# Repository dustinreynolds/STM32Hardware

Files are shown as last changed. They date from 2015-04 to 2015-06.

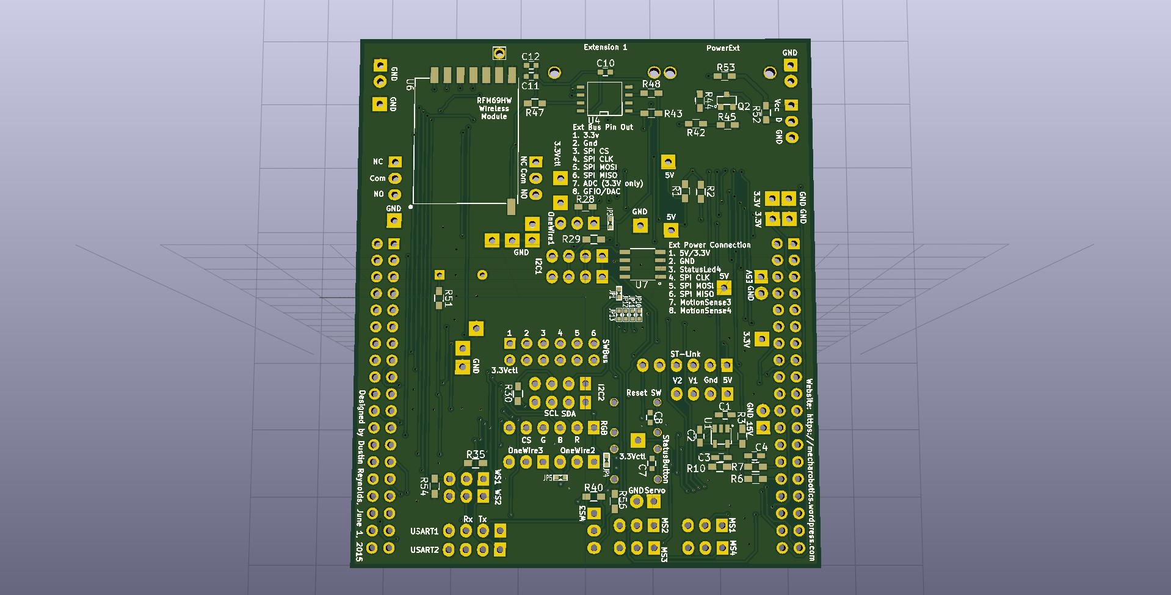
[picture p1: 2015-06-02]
Nucleo_L152RE/ProtoBoard/AB/ProtoBoard_AB_Back.jpg

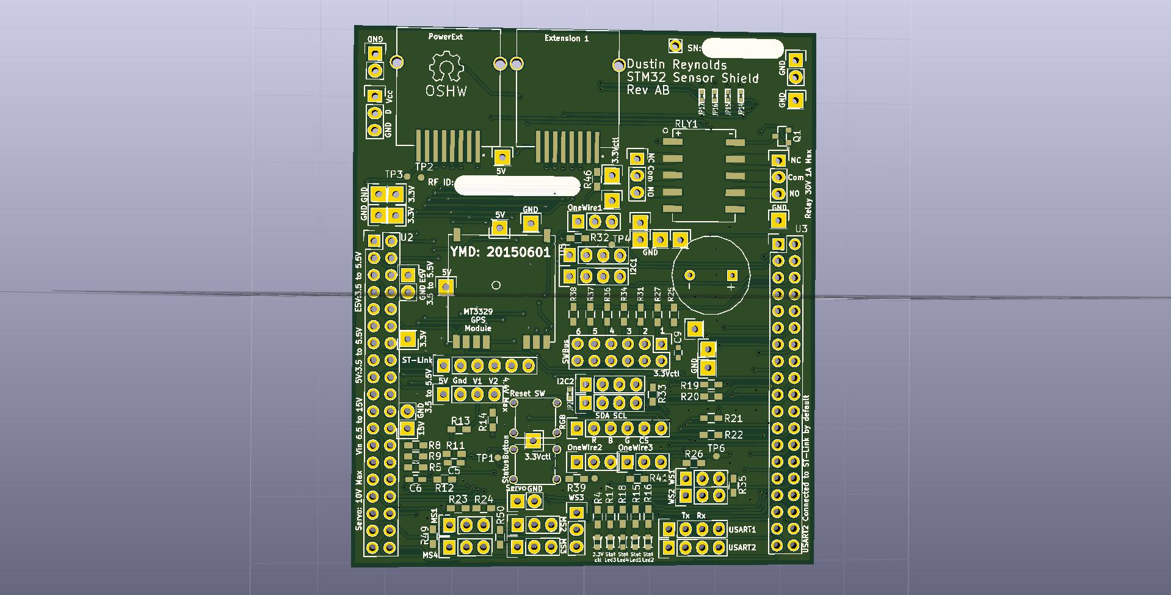
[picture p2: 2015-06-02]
Nucleo_L152RE/ProtoBoard/AB/ProtoBoard_AB_Front.jpg

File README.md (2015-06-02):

# STM32Hardware
Repository for Kicad board development and support libraries

This repository was created on Windows using Kicad built from source using [kicad-winbuilder3.4](https://launchpad.net/kicad-winbuilder).

## Folder Hierarchy 
* Calculations - Brief calculations performed
* kicad_lib - Libraries created for new schematic or pcb objects
* Nucleo_L152RE - contains board designs that have been designed using Kicad build on 2015-05-11 from BZR commit 5650.

## Hardware Releases
So far none of the designs in this repository have been tested and verified to be working.  Footprints have been aligned with the actual components, but until the actual PCB's and the remaining components arrive, this repository should serve as a reference only.  This readme will be updated to reflect the latest testing status.

ProtoBoard Rev AA had the following issues:
	Using 5 pins from morpheo headers that didn't have a pin on them.
	RFM69HW footprint was backwards for part of it.
	See AA schematics for additional notes.

Protoboard Rev AB made the following changes:
	Removed USB, replaced with low voltage relay and fet
	Added Crypto chip ATSHA204A to i2c bus
	Added GPS to I2C bus (those same pins can be used as USART)
	Split schematic into 5 pages to ease readability
	Added 5V in and use that as main power input signal (this leaves programmer unpowered)
	Added additional voltage sense pins on 5V connector for monitoring state of battery pack
	Added 3.3V regulator that can be controlled via enable pin.  This is so SPI/I2C/OneWire devices can be powered off easily.  On board chips have low power requirements when asleep.
	Added additional spare Gnd, 3.3V, 3.3Vctl, and 5.0V lines for expansion.
	Added Servo power input for motionsense 1 and 2 (which are also pwm pins)
	Added piezo buzzer on OneWire3
	Added CS pin for RGB connector since it can be a spare SPI
	Removed mounting holes since this is securely mounted to Nucleo board.

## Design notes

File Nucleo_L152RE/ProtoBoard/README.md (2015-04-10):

# STM32L152RE

The STM32 L series offers low power sleep modes that can be easily utilized to form a network of low power sensing nodes which each have the power of a 32-bit ARM Cortex M3 processor.  This board was designed to leverage these low power modes by adding high power wireless modules with low sleep currents and an on-expansion-board 128 Mb FLASH chip for offline sensor measurements.

THe STM32L152RE has 512KB of flash, 80 KB Ram and ECC backed 16KB EEPROM.  The most compelling feature was the [OpenSTM32](OpenSTM32.org) System Workbench for STM32.  Utilizing an Eclipse base IDE, Eclipse plugins are installed which give you a relatively seamless transition from writing code to debugging it.  The debugger is OpenOCD, utilizing the ST-Link. There are growing pains when transitioning to any platform, but the performance and recent availability of high quality tools make the STM32 a hot platform to start projects on. 

Development boards for a wide range of STM32 processors can be found for under $11.  Although each of those development boards only offer 64 pin packages of each respective processor, much can be done with that core subset of pins.

# Kicad Schematics and Printed Circuit Boards

## ProtoBoard
First Kicad release for the Nucleo-L152RE development board. This development board will serve as a low power platform for performing sensor measurements around my house.  Each STM32 expansion board will contain an RFM69HW wireless transceiver and will be capable of broadcasting events to the wireless network.  A listening device will then notify the owner of the event so that rapid action can occur.

### Event Detection and Alerting
The following events will be monitored
* Water leak (toilets, AC drip pan, Water Heater)
* Room temperature
* Stove burner or oven left on
* Door/window opens or closes
* Plant moisture sensing
* Dryer temperature and timing

### Firmware
The associated firmware can be found at the [SensorNodes Project](https://github.com/dustinreynolds/SensorNodes/tree/develop).  The Git-Flow paradigm is in use, so code can be found in the develop branch until a functioning first release is released, at which point it will be in the master branch (and show up by default on Github).

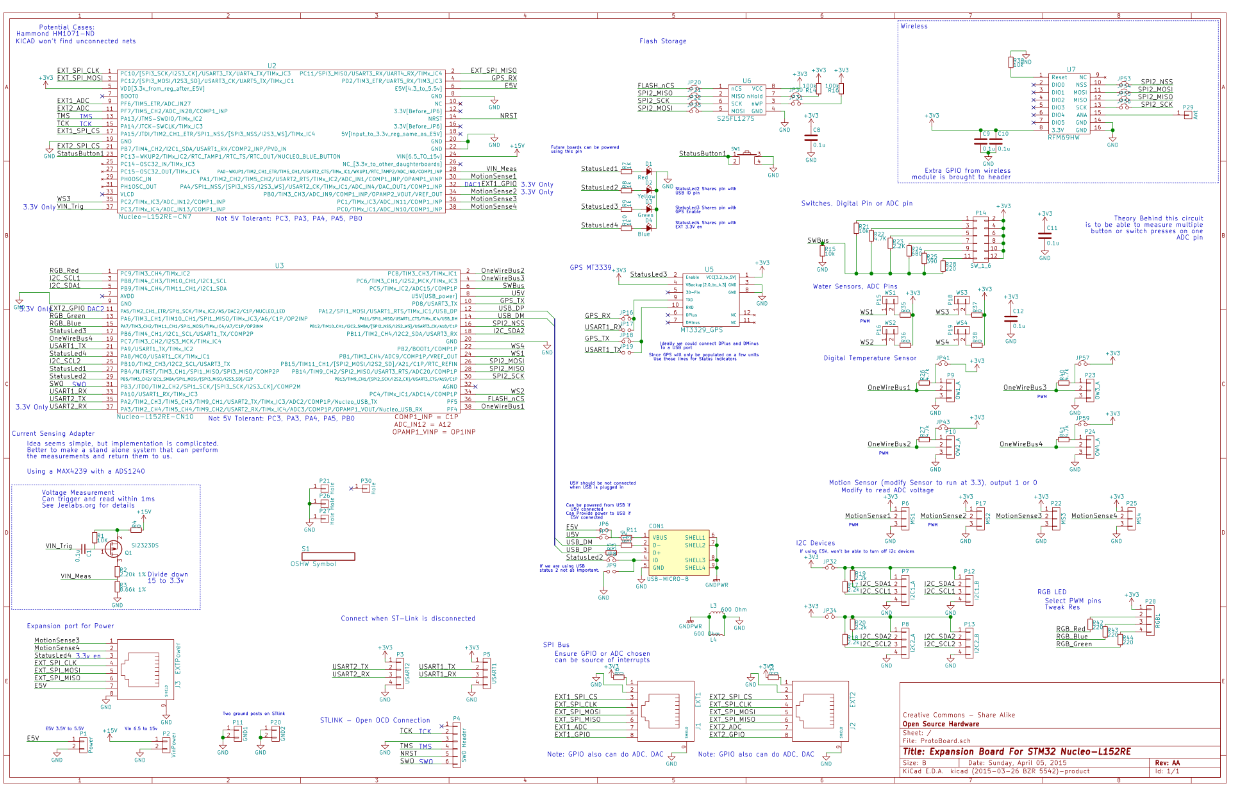
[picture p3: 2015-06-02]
Nucleo_L152RE/ProtoBoard/AA/Schematics.png

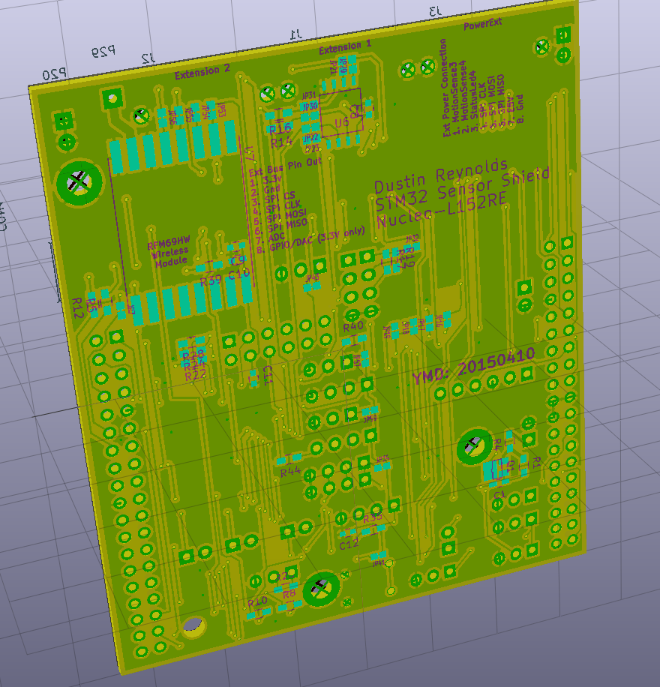
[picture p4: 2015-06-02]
Nucleo_L152RE/ProtoBoard/AA/3d_view_board.png

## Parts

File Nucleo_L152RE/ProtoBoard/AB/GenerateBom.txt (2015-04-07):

To generate bom:
	In Kicad, Click BOM.   Choose bom2csv or bom_cvs and click generate
	In folder, click Update_BOM.bat.  New *.csv will be created.

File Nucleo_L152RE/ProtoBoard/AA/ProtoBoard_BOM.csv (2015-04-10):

Source: | C:/Customers/Dustin/SensorNodes/STM32/EE/Nucleo_L152RE/ProtoBoard/AA/ProtoBoard.sch
Date: | 4/10/2015 3:52:45 PM
Tool: | Eeschema (2015-03-26 BZR 5542)-product
Generator: | dustin_bom_csv_grouped_by_value_with_fp.py
Component Count: | 116
Ref | Quantity | Value | Cmp name | Footprint | Description | Vendor | Datasheet | Digikey Part Number | Digikey URL | Mouser Part Number | Mouser URL | Ebay | Manufacture Part Number
C1, | 1 | 0.1u | C_Small | Capacitors_SMD:C_0603_HandSoldering | Unpolarized capacitor |  | http://www.digikey.com/product-detail/en/GRM188R71C104KA01D/490-1532-1-ND/587771 | 490-1532-1-ND |  |  |  |  | GRM188R71C104KA01D
C10, C9, C8, C11, C12, | 5 | 0.1u | C | Capacitors_SMD:C_0603 | Unpolarized capacitor |  |  | 490-1532-1-ND |  |  |  |  | GRM188R71C104KA01D
CON1, | 1 | USB-MICRO-B | USB-MICRO-B | nucleo:USB_micro_AB | USB Mini B connector |  | http://www.digikey.com/product-detail/en/10104111-0001LF/609-4053-1-ND/2350359 | 609-4053-1-ND | http://www.digikey.com/product-detail/en/10104111-0001LF/609-4053-1-ND |  |  |  | 10104111-0001LF
D1, | 1 | Red | Led_Small | nucleo:LED_0603 | Led |  | http://optoelectronics.liteon.com/upload/download/DS22-2000-223/S_110_LTST-C191KRKT.pdf | 160-1447-1-ND | http://www.digikey.com/product-detail/en/LTST-C191KRKT/160-1447-1-ND/386836 |  |  |  | LTST-C191KRKT
D2, | 1 | Yellow | Led_Small | nucleo:LED_0603 | Led |  | http://optoelectronics.liteon.com/upload/download/DS22-2000-224/S_110_LTST-C191KSKT.pdf | 160-1448-1-ND | http://www.digikey.com/product-detail/en/LTST-C191KSKT/160-1448-1-ND |  |  |  | LTST-C191KSKT
D3, | 1 | Green | Led_Small | nucleo:LED_0603 | Led |  | http://optoelectronics.liteon.com/upload/download/DS22-2000-228/S_110_LTST-C191KGKT.pdf | 160-1446-1-ND | http://www.digikey.com/product-detail/en/LTST-C191KGKT/160-1446-1-ND |  |  |  | LTST-C191KGKT
D4, | 1 | Blue | Led_Small | nucleo:LED_0603 | Led |  | http://optoelectronics.liteon.com/upload/download/DS22-2000-230/S_110_LTST-C191TBKT.pdf | 160-1647-1-ND | http://www.digikey.com/product-detail/en/LTST-C191TBKT/160-1647-1-ND |  |  |  | LTST-C191TBKT
J1, | 1 | EXT1 | RJ45 | nucleo:RJ45_SMD |  |  | http://www.digikey.com/product-detail/en/RJLSE4238101T/RJLSE4238101TTR-ND/1979556 | RJLSE4238101TTR-ND | http://www.digikey.com/product-detail/en/RJLSE4238101T/RJLSE4238101TTR-ND/1979556 |  |  |  | RJLSE4238101T
J2, | 1 | EXT2 | RJ45 | nucleo:RJ45_SMD |  |  | http://www.digikey.com/product-detail/en/RJLSE4238101T/RJLSE4238101TTR-ND/1979556 | RJLSE4238101TTR-ND | http://www.digikey.com/product-detail/en/RJLSE4238101T/RJLSE4238101TTR-ND/1979556 |  |  |  | RJLSE4238101T
J3, | 1 | EXTPower | RJ45 | nucleo:RJ45_SMD |  |  | http://www.digikey.com/product-detail/en/RJLSE4238101T/RJLSE4238101TTR-ND/1979556 | RJLSE4238101TTR-ND | http://www.digikey.com/product-detail/en/RJLSE4238101T/RJLSE4238101TTR-ND/1979556 |  |  |  | RJLSE4238101T
JP19, JP17, JP9, JP6, | 4 | Jumper_NO_Small | Jumper_NO_Small | nucleo:SB_NO | Jumper normally open
JP53, JP54, JP55, JP56, JP20, JP21, JP22, JP23, JP30, JP31, JP16, JP18, JP8, JP34, JP32, JP7, JP41, JP57, JP59, JP43, | 20 | Jumper_NC_Small | Jumper_NC_Small | nucleo:SB_NC | Jumper normally close
L4, L3, | 2 | 600 Ohm | L_Small | Resistors_SMD:R_0603_HandSoldering | Inductor |  | http://www.digikey.com/product-detail/en/MI0603J601R-10/240-2371-1-ND/806731 | 240-2371-1-ND | http://www.digikey.com/product-detail/en/MI0603J601R-10/240-2371-1-ND/ |  |  |  | MI0603J601R-10
P1, | 1 | Power | CONN_01X02 | Pin_Headers:Pin_Header_Straight_1x02
P10, | 1 | OW2_A | CONN_01X03 | Pin_Headers:Pin_Header_Straight_1x03
P11, | 1 | GND1 | CONN_01X02 | Pin_Headers:Pin_Header_Straight_1x02
P12, | 1 | I2C1_B | CONN_01X04 | Pin_Headers:Pin_Header_Straight_1x04
P13, | 1 | I2C2_B | CONN_01X04 | Pin_Headers:Pin_Header_Straight_1x04
P14, | 1 | SW_1_6 | CONN_02X06 | Pin_Headers:Pin_Header_Straight_2x06
P15, | 1 | WS1 | CONN_01X02 | Pin_Headers:Pin_Header_Straight_1x02
P16, | 1 | WS2 | CONN_01X02 | Pin_Headers:Pin_Header_Straight_1x02
P17, | 1 | MS2 | CONN_01X03 | Pin_Headers:Pin_Header_Straight_1x03
P18, | 1 | WS3 | CONN_01X02 | Pin_Headers:Pin_Header_Straight_1x02
P19, | 1 | WS4 | CONN_01X02 | Pin_Headers:Pin_Header_Straight_1x02
P2, | 1 | VinPower | CONN_01X02 | Pin_Headers:Pin_Header_Straight_1x02
P20, | 1 | GND2 | CONN_01X02 | Pin_Headers:Pin_Header_Straight_1x02
P21, P26, P27, | 3 | Hole | CONN_01X01 | nucleo:plat_hole_4_20
P22, | 1 | MS3 | CONN_01X03 | Pin_Headers:Pin_Header_Straight_1x03
P23, | 1 | OW3_A | CONN_01X03 | Pin_Headers:Pin_Header_Straight_1x03
P24, | 1 | OW4_A | CONN_01X03 | Pin_Headers:Pin_Header_Straight_1x03
P25, | 1 | MS4 | CONN_01X03 | Pin_Headers:Pin_Header_Straight_1x03
P28, | 1 | RGB1 | CONN_01X04 | Pin_Headers:Pin_Header_Straight_1x04
P29, | 1 | Ant | CONN_01X01 | Pin_Headers:Pin_Header_Straight_1x01
P3, | 1 | USART2 | CONN_01X04 | Pin_Headers:Pin_Header_Straight_1x04
P30, | 1 | Hole | CONN_01X01 | Mounting_Holes:MountingHole_3mm
P4, | 1 | SWD Header | CONN_01X06 | Pin_Headers:Pin_Header_Straight_1x06
P5, | 1 | USART1 | CONN_01X04 | Pin_Headers:Pin_Header_Straight_1x04
P6, | 1 | MS1 | CONN_01X03 | Pin_Headers:Pin_Header_Straight_1x03
P7, | 1 | I2C1_A | CONN_01X04 | Pin_Headers:Pin_Header_Straight_1x04
P8, | 1 | I2C2_A | CONN_01X04 | Pin_Headers:Pin_Header_Straight_1x04
P9, | 1 | OW1_A | CONN_01X03 | Pin_Headers:Pin_Header_Straight_1x03
Q1, | 1 | SI2323DS | Q_PMOS_GSD | nucleo:TO-236 | Transistor P-MOSFET (general) |  | http://www.vishay.com/docs/72024/72024.pdf | SI2323DS-T1-E3CT-ND |  |  |  |  | SI2323DS-T1-E3
R1, | 1 | 10K | R_Small | Resistors_SMD:R_0603_HandSoldering | Resistor |  |  | P10KGCT-ND | http://www.digikey.com/product-detail/en/ERJ-3GEYJ103V/P10KGCT-ND/134717 |  |  |  | ERJ-3GEYJ103V
R14, R16, | 2 | 100k | R_Small | Resistors_SMD:R_0603_HandSoldering | Resistor |  |  | RMCF0603FT100KTR-ND | http://www.digikey.com/product-detail/en/RMCF0603FT100K/RMCF0603FT100KTR-ND |  |  |  | CRCW0603100KFKEA
R2, | 1 | 2.20k 1% | R_Small | Resistors_SMD:R_0603_HandSoldering | Resistor |  |  | P2.20KHCT-ND |  |  |  |  | ERJ-3EKF2201V
R20, R18, R17, R19, | 4 | 2.2k | R_Small | Resistors_SMD:R_0603_HandSoldering | Resistor |  |  | P2.2KGCT-ND |  |  |  |  | ERJ-3GEYJ222V
R21, R15, R39, | 3 | 10k | R_Small | Resistors_SMD:R_0603_HandSoldering | Resistor |  |  | P10KGCT-ND | http://www.digikey.com/product-detail/en/ERJ-3GEYJ103V/P10KGCT-ND/134717 |  |  |  | ERJ-3GEYJ103V
R22, | 1 | 4.7K | R_Small | Resistors_SMD:R_0603_HandSoldering | Resistor |  |  | P4.7KGCT-ND | http://www.digikey.com/product-detail/en/ERJ-3GEYJ472V/P4.7KGCT-ND/135199 |  |  |  | ERJ-3GEYJ472V
R23, | 1 | 2.2K | R_Small | Resistors_SMD:R_0603_HandSoldering | Resistor |  |  | P2.2KGCT-ND |  |  |  |  | ERJ-3GEYJ222V
R24, | 1 | 680 | R_Small | Resistors_SMD:R_0603_HandSoldering | Resistor |  |  | P680GCT-ND |  |  |  |  | CRCW0603680RFKEA
R25, | 1 | 390 | R_Small | Resistors_SMD:R_0603_HandSoldering | Resistor |  |  | P390GCT-ND |  |  |  |  | ERJ-3GEYJ390V
R26, R27, R40, R41, | 4 | 4.7k | R_Small | Resistors_SMD:R_0603_HandSoldering | Resistor |  |  | P4.7KGCT-ND |  |  |  |  | ERJ-3GEYJ472V
R28, R42, R43, R44, | 4 | 220 | R_Small | Resistors_SMD:R_0603_HandSoldering | Resistor |  |  | P220GCT-ND |  |  |  |  | ERJ-3GEYJ222V
R3, | 1 | 8.66k 1% | R_Small | Resistors_SMD:R_0603_HandSoldering | Resistor |  |  | P8.66KHCT-ND |  |  |  |  | ERJ-3EKF8661V
R35, R36, R38, R37, R6, R13, R11, R4, | 8 | 0 | R_Small | Resistors_SMD:R_0603_HandSoldering | Resistor |  |  | P0.0GCT-ND |  |  |  |  | ERJ-3GEY0R00V
R5, R12, | 2 | 33 | R_Small | Resistors_SMD:R_0603_HandSoldering | Resistor |  |  | P33HCT-ND |  |  |  |  | ERJ-3EKF33R0V
R7, | 1 | 1K | R_Small | Resistors_SMD:R_0603_HandSoldering | Resistor |  |  | P1.0KGCT-ND |  |  |  |  | ERJ-3GEYJ102V
R8, R9, R10, | 3 | 1k | R_Small | Resistors_SMD:R_0603_HandSoldering | Resistor |  |  | P1.0KGCT-ND |  |  |  |  | ERJ-3GEYJ102V
S1, | 1 | OSHW Symbol | Symbol | Symbols:Symbol_OSHW-Logo_SilkScreen
SW1, | 1 | MomentarySwitch | MomentarySwitch | nucleo:Tact_switch | 4 Pin momentary Switch |  |  | 450-1650-ND | http://www.digikey.com/product-detail/en/1825910-6/450-1650-ND |  |  |  | 1825910-6
U2, | 1 | Nucleo-L152RE-CN7 | Nucleo-L152RE-CN7 | Pin_Headers:Pin_Header_Straight_2x19 | Nucleo-L152RE Morpho CN7 Connector |  |  | 497-14363-ND |  |  |  |  | NUCLEO-L152RE
U3, | 1 | Nucleo-L152RE-CN10 | Nucleo-L152RE-CN10 | Pin_Headers:Pin_Header_Straight_2x19 | Nucleo-L152RE Morpo Connector CN10 |  |  |  |  |  |  | 40 2.54 female round header pin
U5, | 1 | MT3329_GPS | MT3329_GPS | nucleo:MT3329 | MT3329 10Hz GPS
U6, | 1 | S25FL127S | S25FL127S | nucleo:SOIC-8-FLASH | S25FL127S 128 Mbit Flash 2.7 to 3.6v |  | http://www.digikey.com/product-detail/en/SI2323DS-T1-E3/SI2323DS-T1-E3CT-ND | 1274-1045-ND | http://www.digikey.com/product-detail/en/S25FL127SABMFI101/1274-1045-ND/4142071 |  |  |  | S25FL127SABMFI101
U7, | 1 | RFM69HW | RFM69HW | nucleo:RFM69HW | Hope RF RFM69HW Wireless Module |  |  |  |  |  |  | RFM69HW 915MHz

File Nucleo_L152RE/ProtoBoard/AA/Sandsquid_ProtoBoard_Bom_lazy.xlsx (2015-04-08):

 | www.sandsquid.com |  |  | BOM NAME HERE
MANDATORY Part number as appears in the manufacturer catalogue | OPTIONAL Name of manufacturer | MANDATORY How many units on a PCB | OPTIONAL Names under which this part appears in the design files | OPTIONAL Part description | OPTIONAL Supplier-specific part numbers. Note that we always search a part in all suppliers, regardless of whether a specific P/N has been provided in these columns. Using these fields can yield more accurate results for parts we are having trouble locating, but it is usually not needed and can be left blank.
Part Number | Manufacturer | Qty | Reference | Description | Digikey | Mouser | Newark | Arrow | Avnet | Allied
GRM188R71C104KA01D |  | 1 | C1,
GRM188R71C104KA01D |  | 5 | C10, C9, C8, C11, C12,
10104111-0001LF |  | 1 | CON1,
LTST-C191KRKT |  | 1 | D1,
LTST-C191KSKT |  | 1 | D2,
LTST-C191KGKT |  | 1 | D3,
LTST-C191TBKT |  | 1 | D4,
RJLSE4238101T |  | 1 | J1,
RJLSE4238101T |  | 1 | J2,
RJLSE4238101T |  | 1 | J3,
 |  | 4 | JP19, JP17, JP9, JP6,
 |  | 20 | JP53, JP54, JP55, JP56, JP20, JP21, JP22, JP23, JP30, JP31, JP16, JP18, JP8, JP34, JP32, JP7, JP41, JP57, JP59, JP43,
MI0603J601R-10 |  | 2 | L4, L3,
 |  | 1 | P1,
 |  | 1 | P10,
 |  | 1 | P11,
 |  | 1 | P12,
 |  | 1 | P13,
 |  | 1 | P14,
 |  | 1 | P15,
 |  | 1 | P16,
 |  | 1 | P17,
 |  | 1 | P18,
 |  | 1 | P19,
 |  | 1 | P2,
 |  | 1 | P20,
 |  | 3 | P21, P26, P27,
 |  | 1 | P22,
 |  | 1 | P23,
 |  | 1 | P24,
 |  | 1 | P25,
 |  | 1 | P28,
 |  | 1 | P29,
 |  | 1 | P3,
 |  | 1 | P30,
 |  | 1 | P4,
 |  | 1 | P5,
 |  | 1 | P6,
 |  | 1 | P7,
 |  | 1 | P8,
 |  | 1 | P9,
SI2323DS-T1-E3 |  | 1 | Q1,
ERJ-3GEYJ103V |  | 1 | R1,
CRCW0603100KFKEA |  | 2 | R14, R16,
ERJ-3EKF2201V |  | 1 | R2,
ERJ-3GEYJ222V |  | 4 | R20, R18, R17, R19,
ERJ-3GEYJ103V |  | 3 | R21, R15, R39,
ERJ-3GEYJ472V |  | 1 | R22,
ERJ-3GEYJ222V |  | 1 | R23,
CRCW0603680RFKEA |  | 1 | R24,
ERJ-3GEYJ390V |  | 1 | R25,
ERJ-3GEYJ472V |  | 4 | R26, R27, R40, R41,
ERJ-3GEYJ222V |  | 4 | R28, R42, R43, R44,
ERJ-3EKF8661V |  | 1 | R3,
ERJ-3GEY0R00V |  | 7 | R35, R36, R38, R37, R6, R13, R11,
ERJ-3EKF33R0V |  | 2 | R5, R12,
ERJ-3GEYJ102V |  | 1 | R7,
ERJ-3GEYJ102V |  | 3 | R8, R9, R10,
 |  | 1 | S1,
1825910-6 |  | 1 | SW1,
NUCLEO-L152RE |  | 0 | U2,
 |  | 1 | U3,
 |  | 1 | U5,
S25FL127SABMFI101 |  | 1 | U6,
 |  | 0 | U7,

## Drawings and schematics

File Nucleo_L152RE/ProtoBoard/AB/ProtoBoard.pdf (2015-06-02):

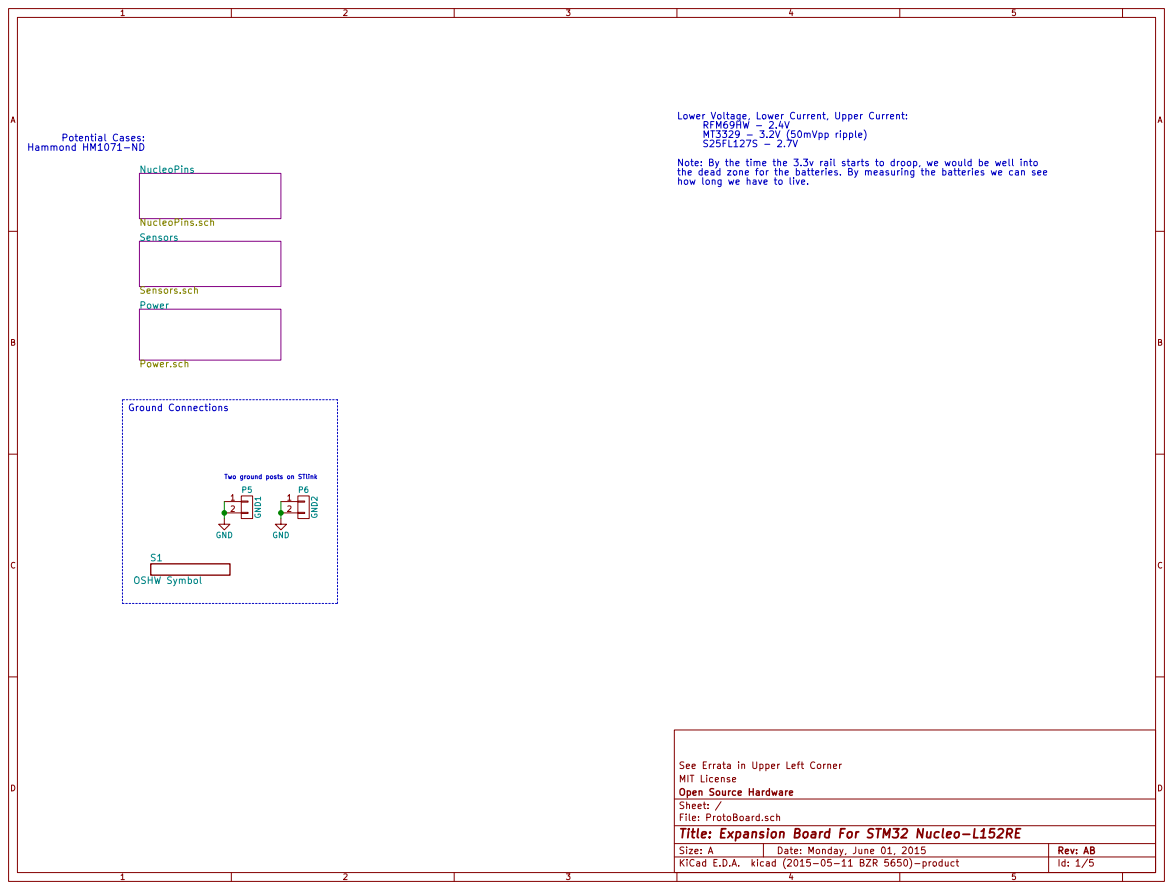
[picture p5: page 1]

S1 OSHW Symbol Power Power.sch NucleoPins NucleoPins.sch Sensors Sensors.sch Ground Connections

Lower Voltage, Lower Current, Upper Current:
RFM69HW - 2.4V
MT3329 - 3.2V (50mVpp ripple)
S25FL127S - 2.7V Note: By the time the 3.3v rail starts to droop, we would be well into

the dead zone for the batteries. By measuring the batteries we can see
how long we have to live.

Two ground posts on STlink

File: ProtoBoard.sch Sheet: / Open Source Hardware MIT License See Errata in Upper Left Corner

Id: 1/5 Title: Expansion Board For STM32 Nucleo-L152RE

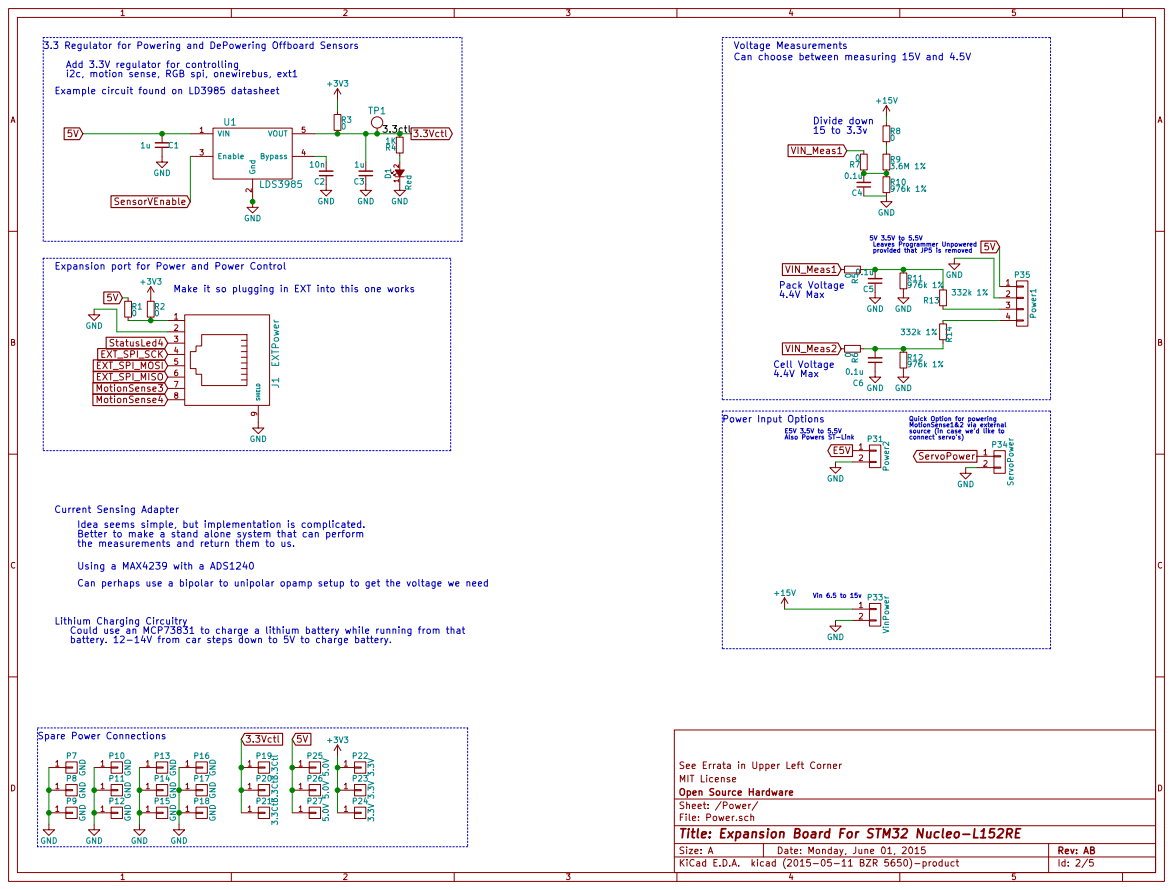
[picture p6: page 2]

3.3 Regulator for Powering and DePowering Offboard Sensors
3.3ctl Add 3.3V regulator for controlling
Example circuit found on LD3985 datasheet

GND GND GND GND Can choose between measuring 15V and 4.5V
15 to 3.3v 12 P33 VinPower GND GND
VIN_Meas1

+15VR8 0 Make it so plugging in EXT into this one works

the measurements and return them to us. Using a MAX4239 with a ADS1240 MotionSense3 MotionSense4 StatusLed4 EXT_SPI_SCK

Current Sensing Adapter
Idea seems simple, but implementation is complicated.
Better to make a stand alone system that can perform

Could use an MCP73831 to charge a lithium battery while running from that
battery. 12-14V from car steps down to 5V to charge battery.

File: Power.sch Sheet: /Power/ Open Source Hardware MIT License See Errata in Upper Left Corner

Id: 2/5 Title: Expansion Board For STM32 Nucleo-L152RE

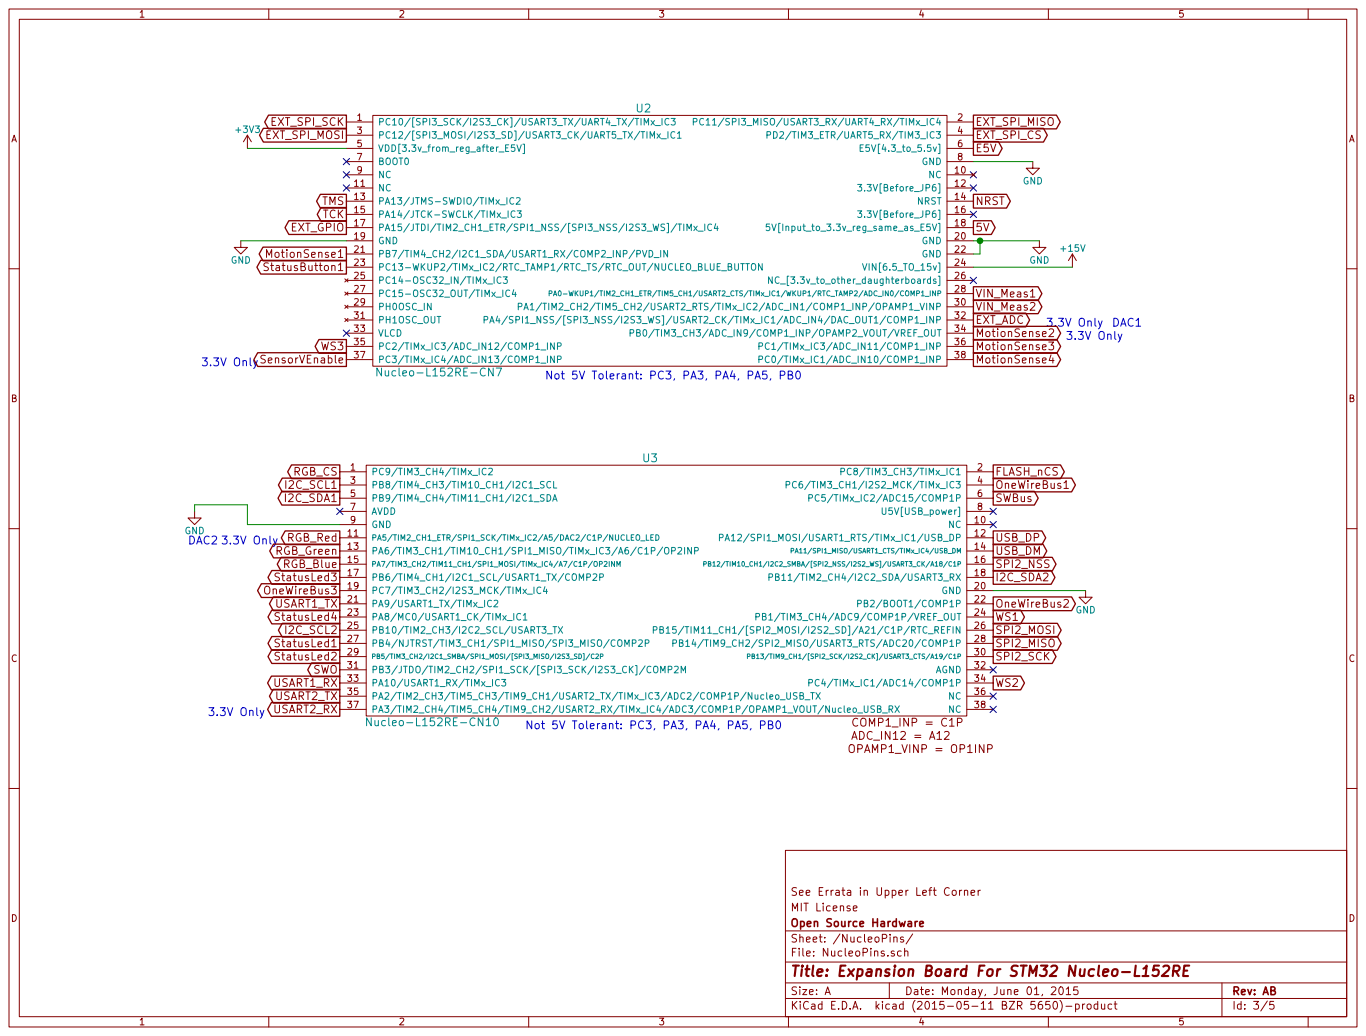
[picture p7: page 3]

File: NucleoPins.sch Sheet: /NucleoPins/ Open Source Hardware MIT License See Errata in Upper Left Corner

Id: 3/5 Title: Expansion Board For STM32 Nucleo-L152RE

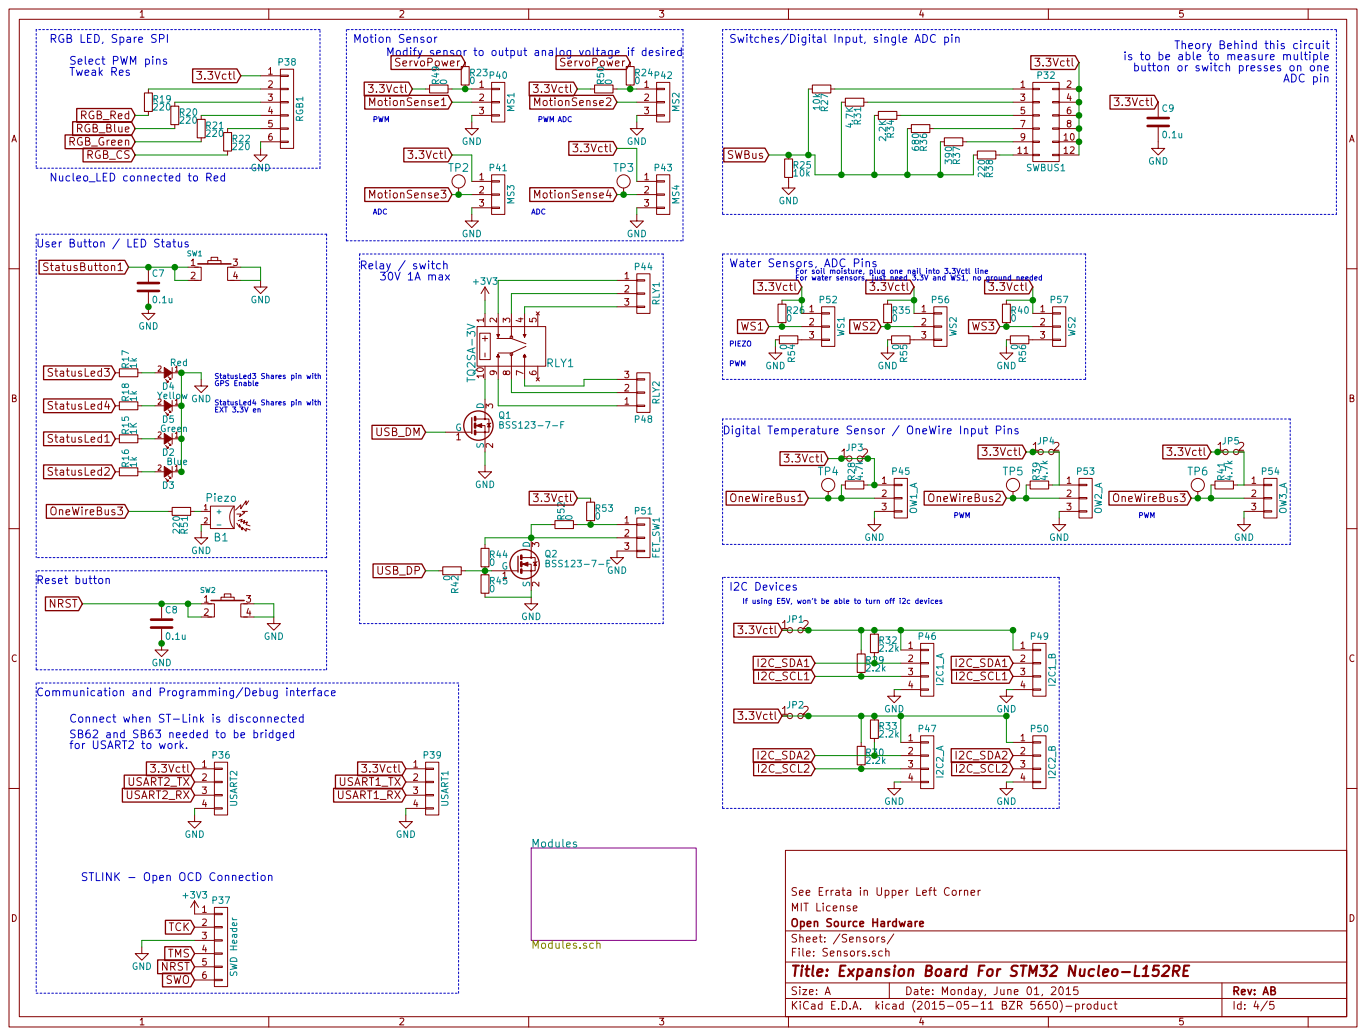
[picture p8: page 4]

3 P43 MS4 GND RGB LED, Spare SPIR19

Switches/Digital Input, single ADC pin

is to be able to measure multiple
button or switch presses on one

Water Sensors, ADC Pins

For soil moisture, plug one nail into 3.3Vctl line 1

Digital Temperature Sensor / OneWire Input Pins

Connect when ST-Link is disconnected
SB62 and SB63 needed to be bridged

File: Sensors.sch Sheet: /Sensors/ Open Source Hardware MIT License See Errata in Upper Left Corner

Id: 4/5 Title: Expansion Board For STM32 Nucleo-L152RE

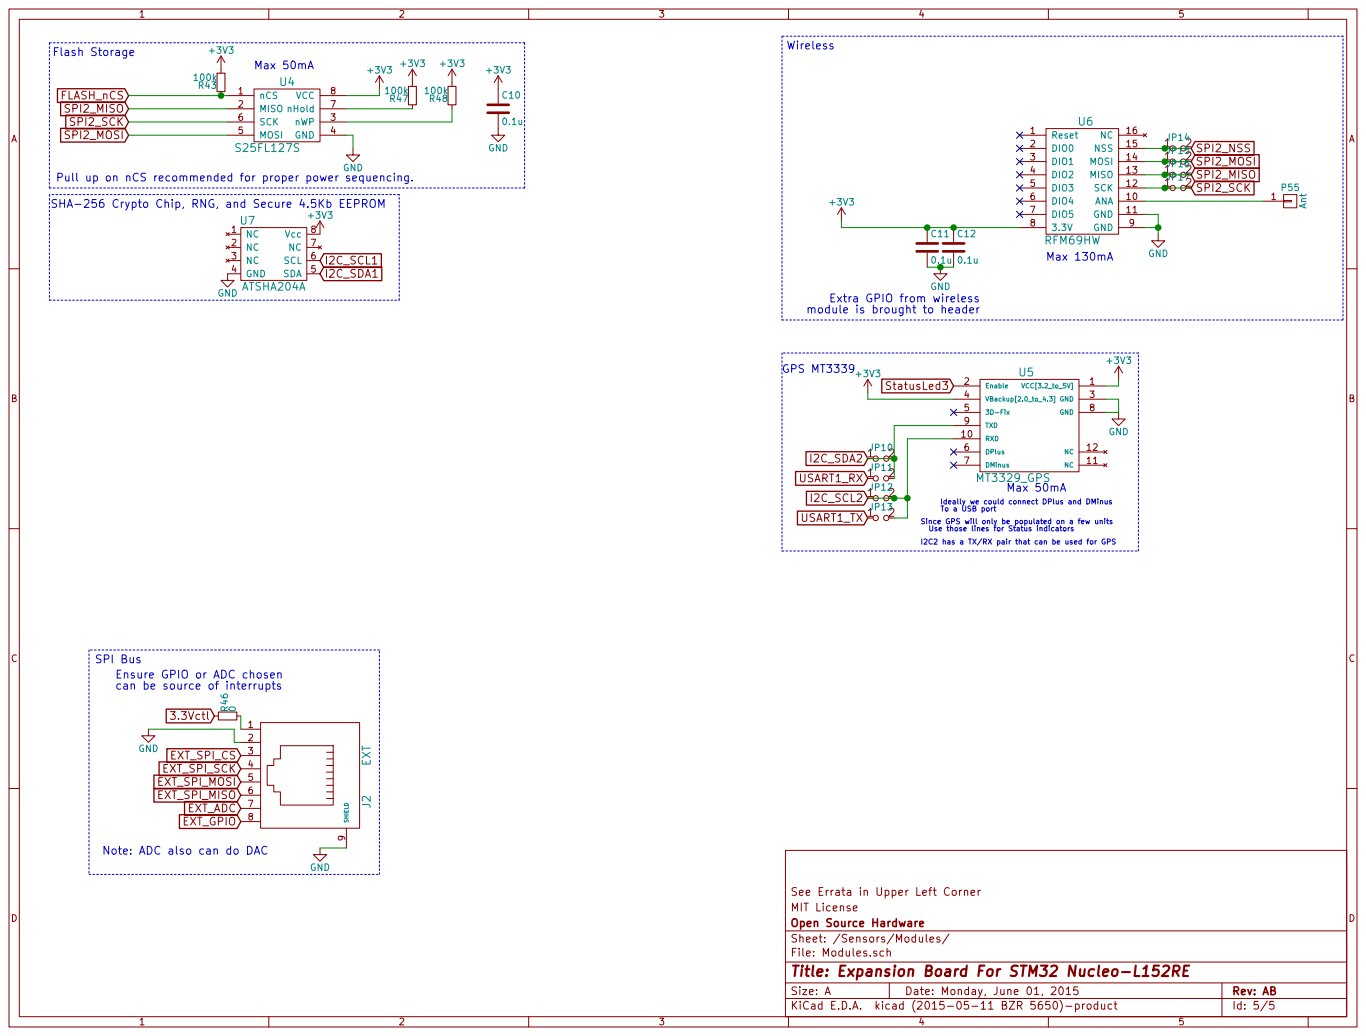
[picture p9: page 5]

+3V3 GND SHA-256 Crypto Chip, RNG, and Secure 4.5Kb EEPROM

Ideally we could connect DPlus and DMinus To a USB port +3V3 GPS MT3339

I2C2 has a TX/RX pair that can be used for GPS Max 50mA

Since GPS will only be populated on a few units

can be source of interrupts

Note: ADC also can do DAC

File: Modules.sch Sheet: /Sensors/Modules/ Open Source Hardware MIT License See Errata in Upper Left Corner

Id: 5/5 Title: Expansion Board For STM32 Nucleo-L152RE

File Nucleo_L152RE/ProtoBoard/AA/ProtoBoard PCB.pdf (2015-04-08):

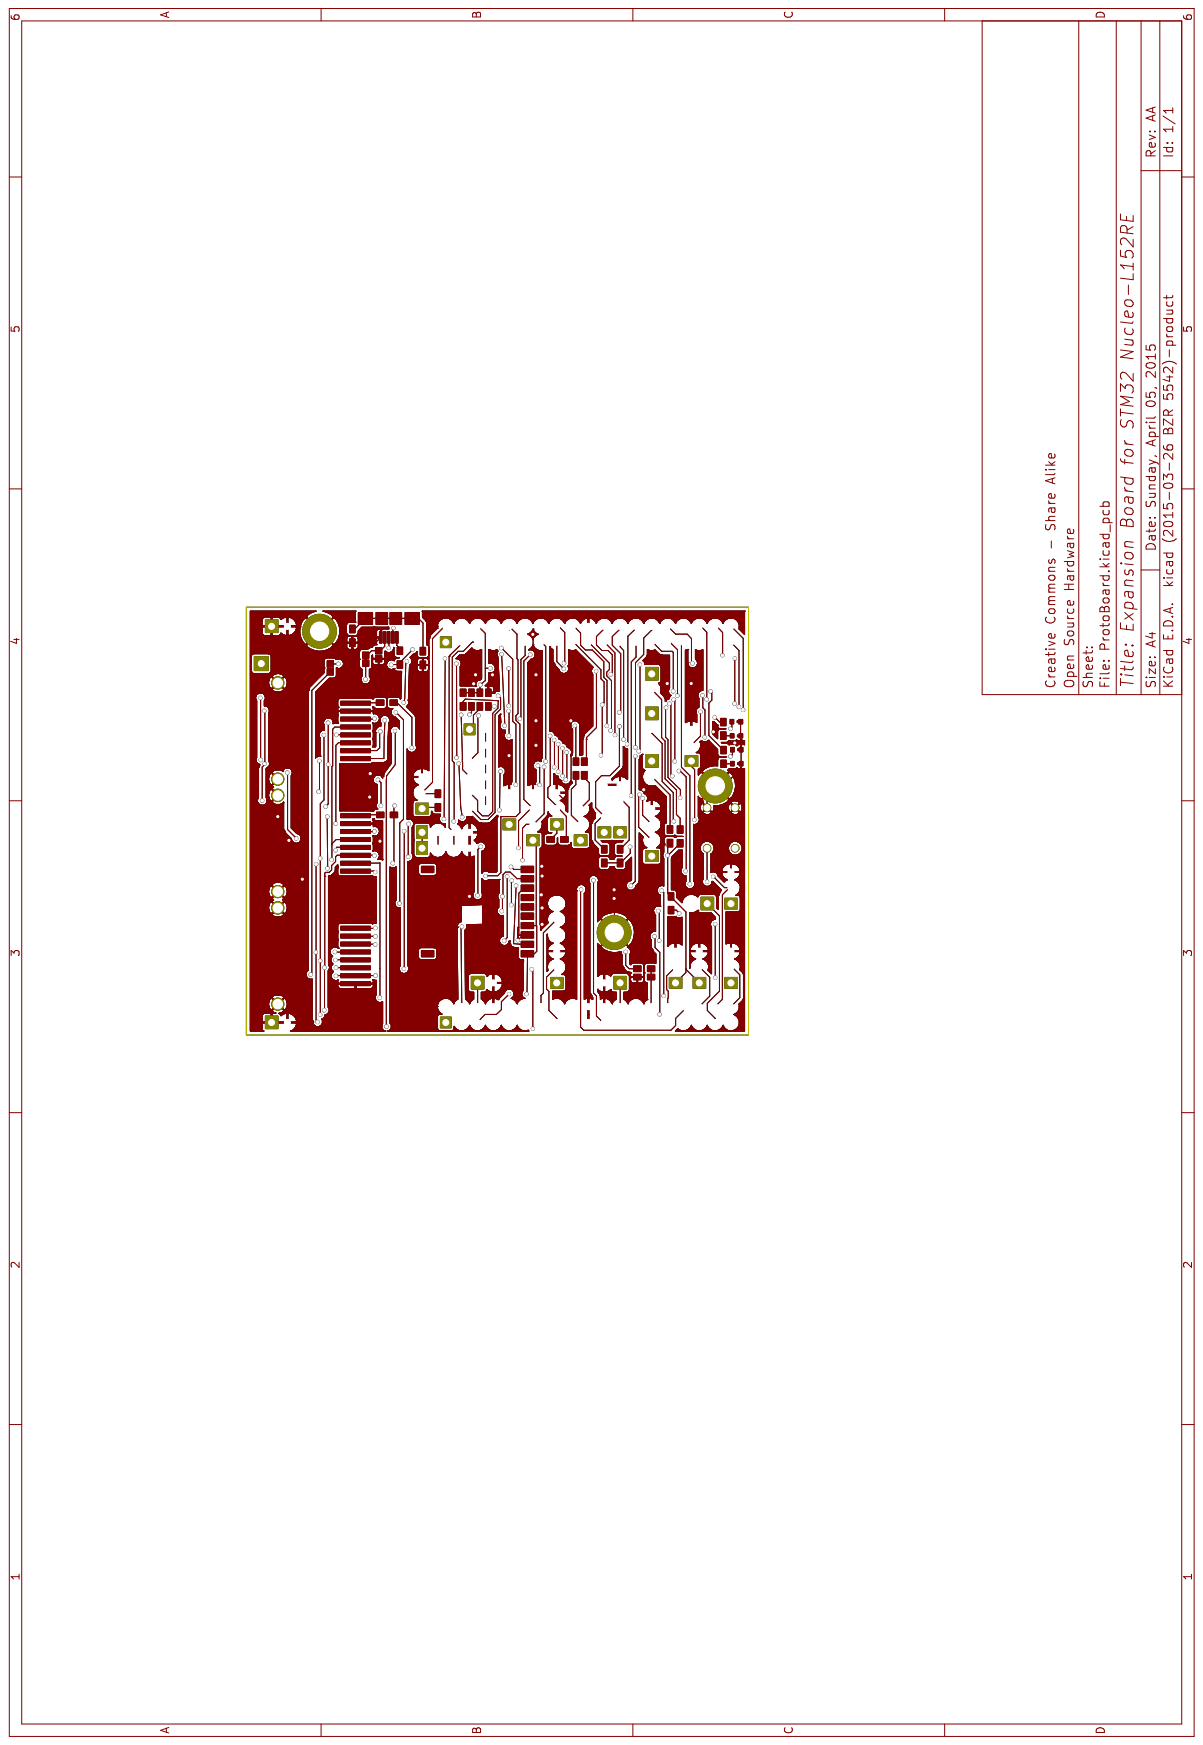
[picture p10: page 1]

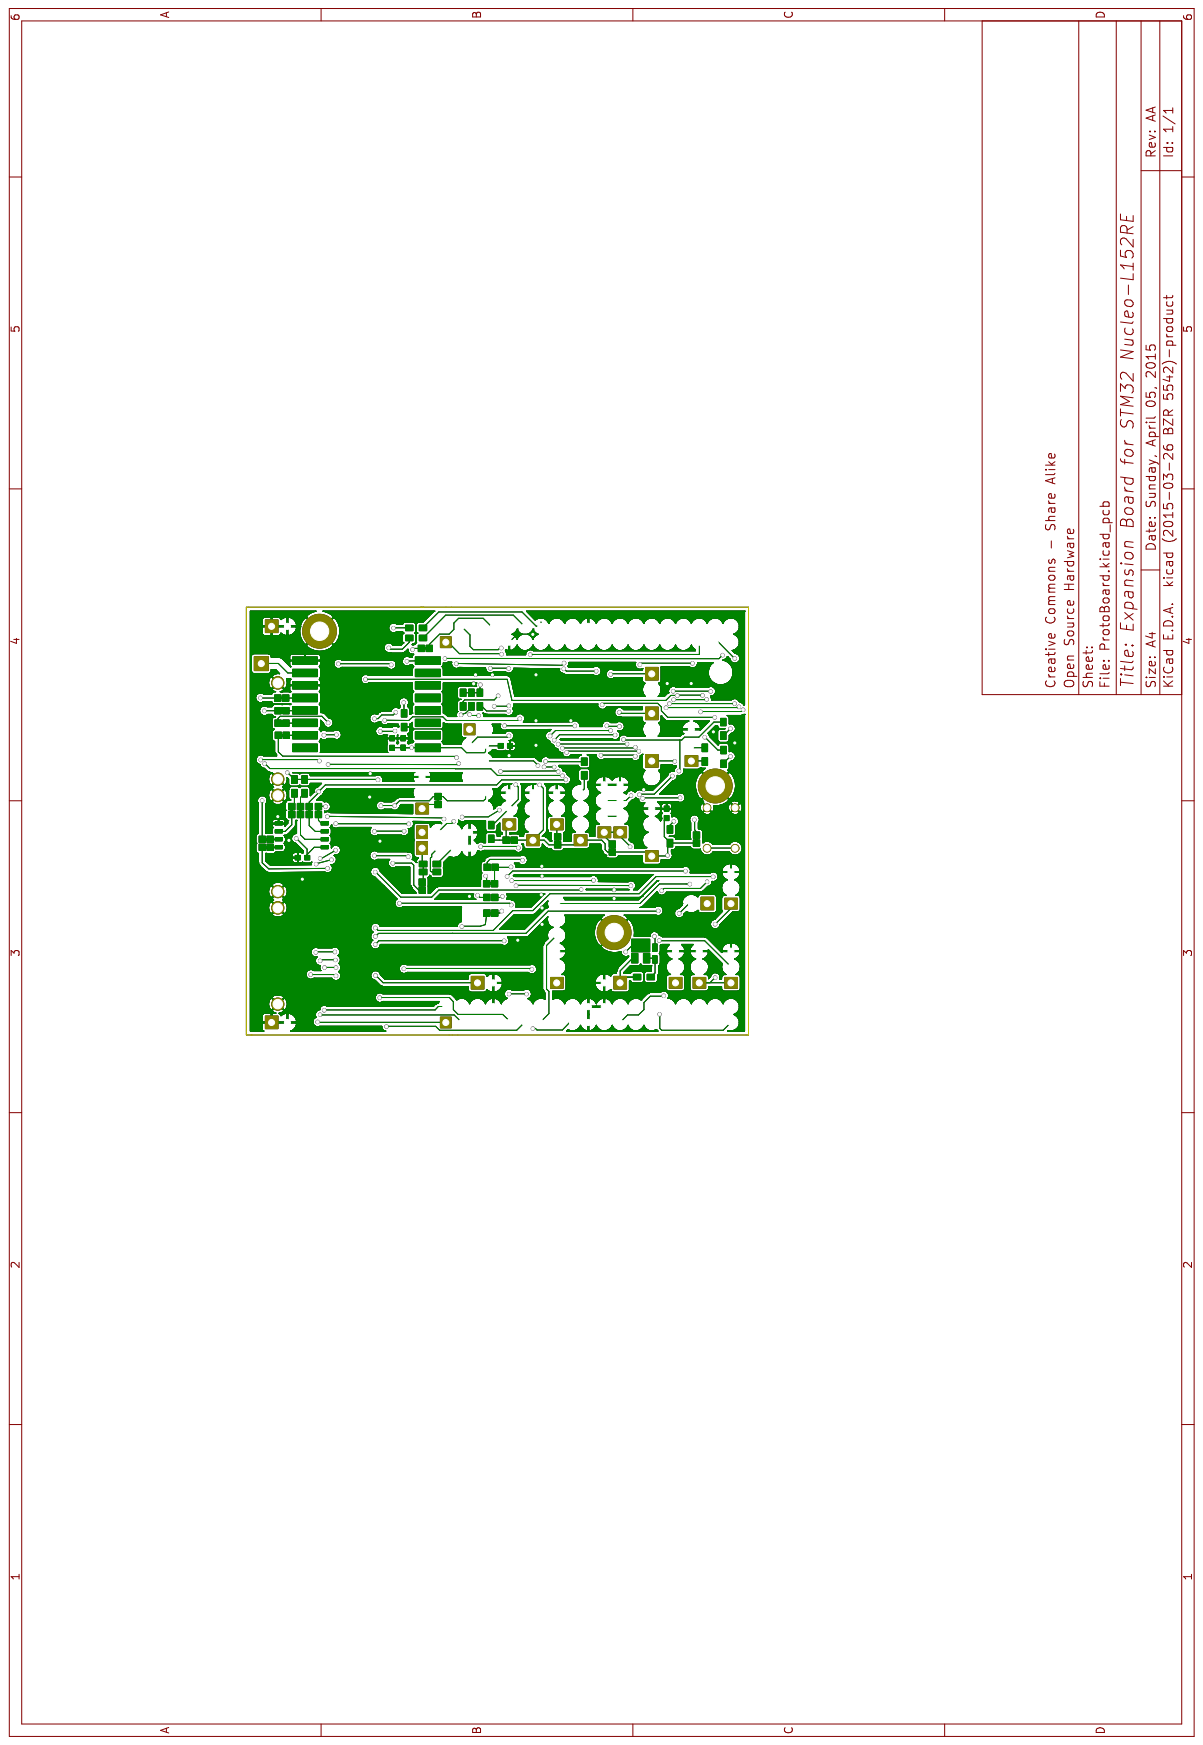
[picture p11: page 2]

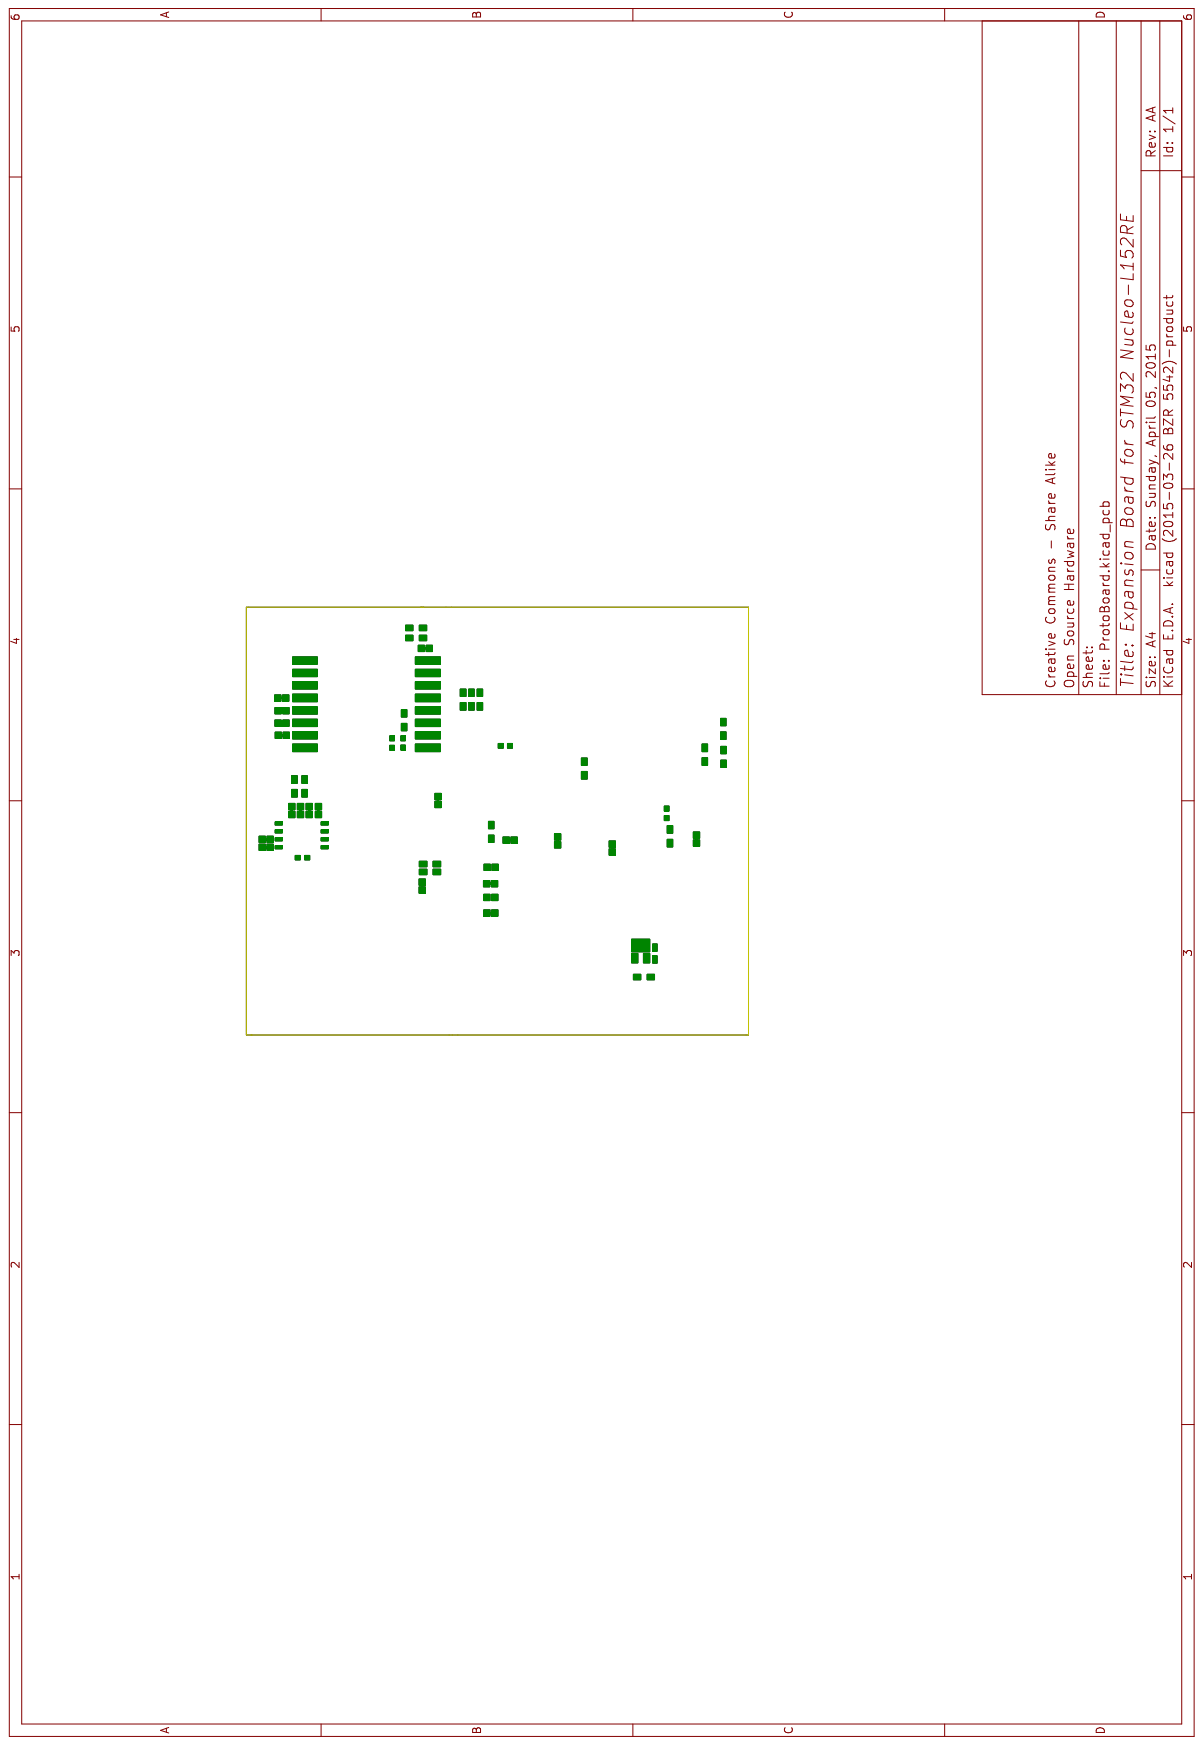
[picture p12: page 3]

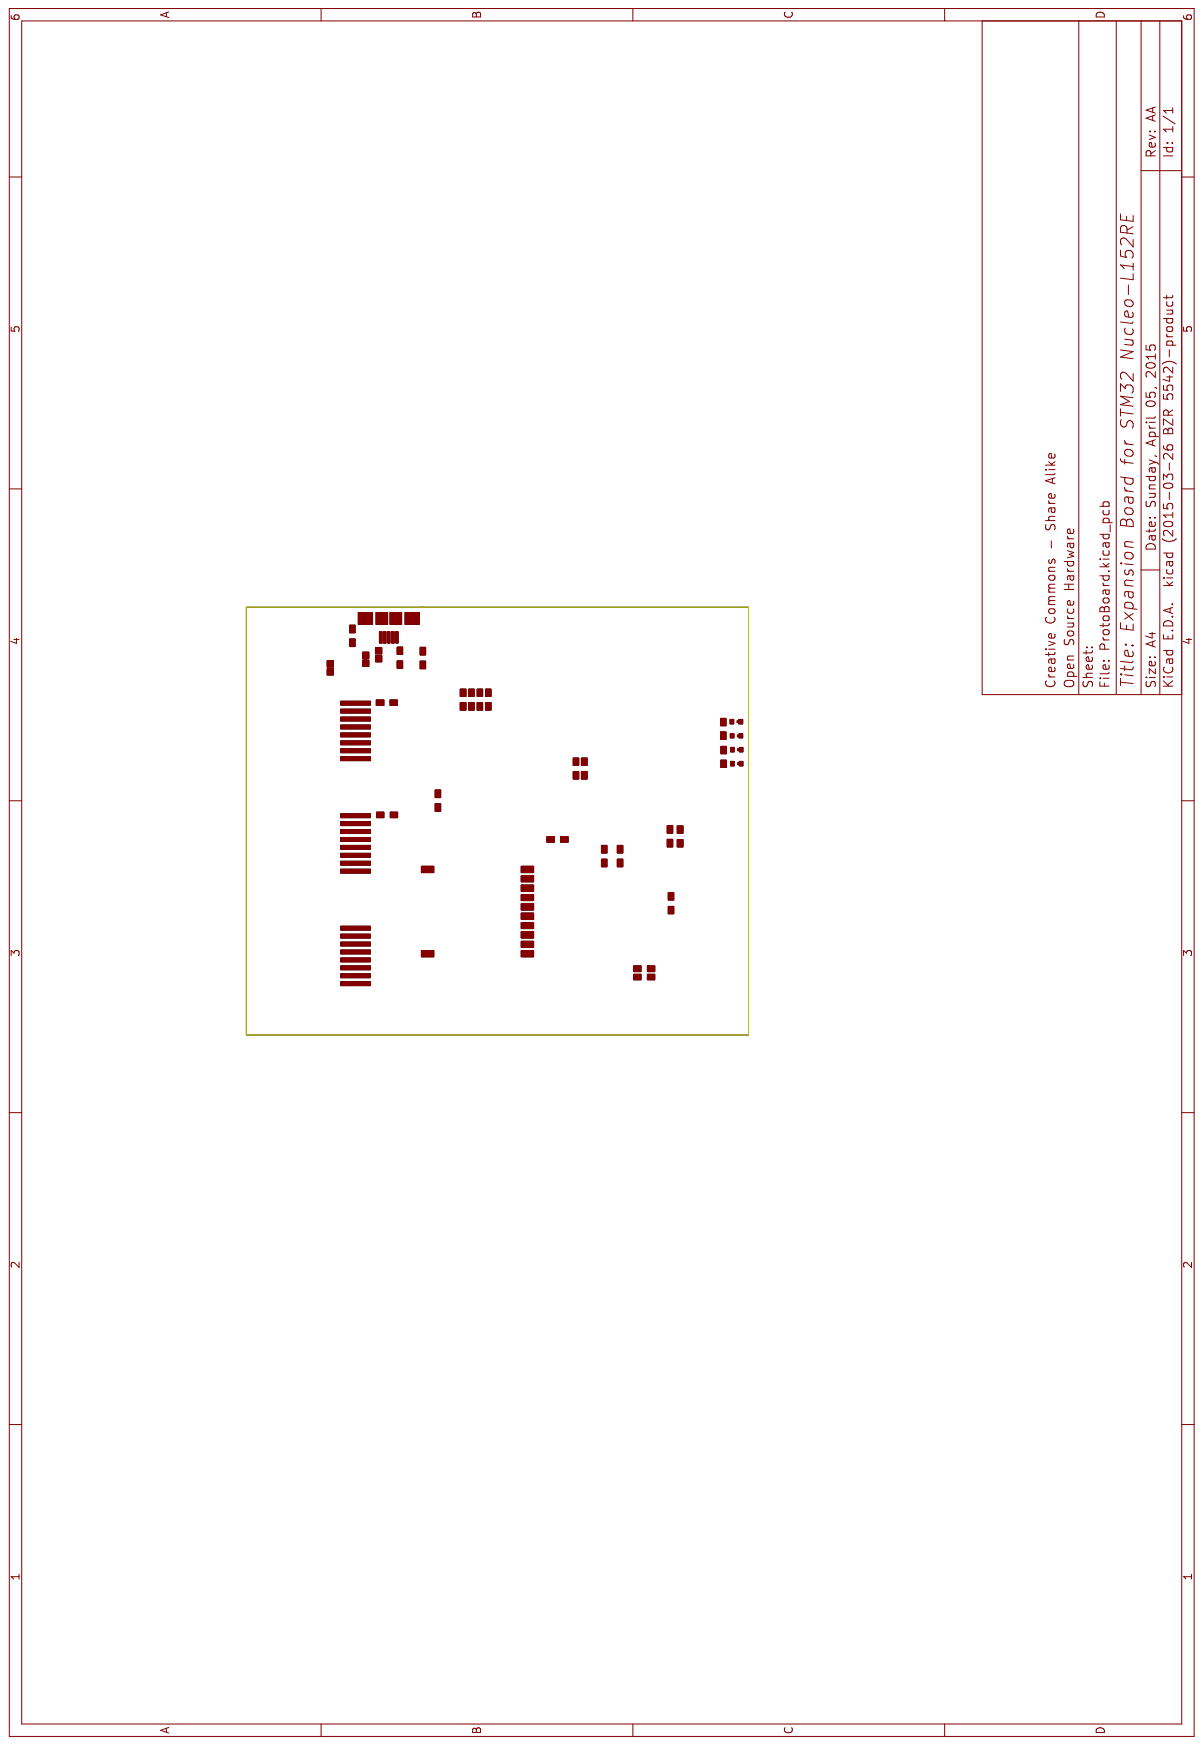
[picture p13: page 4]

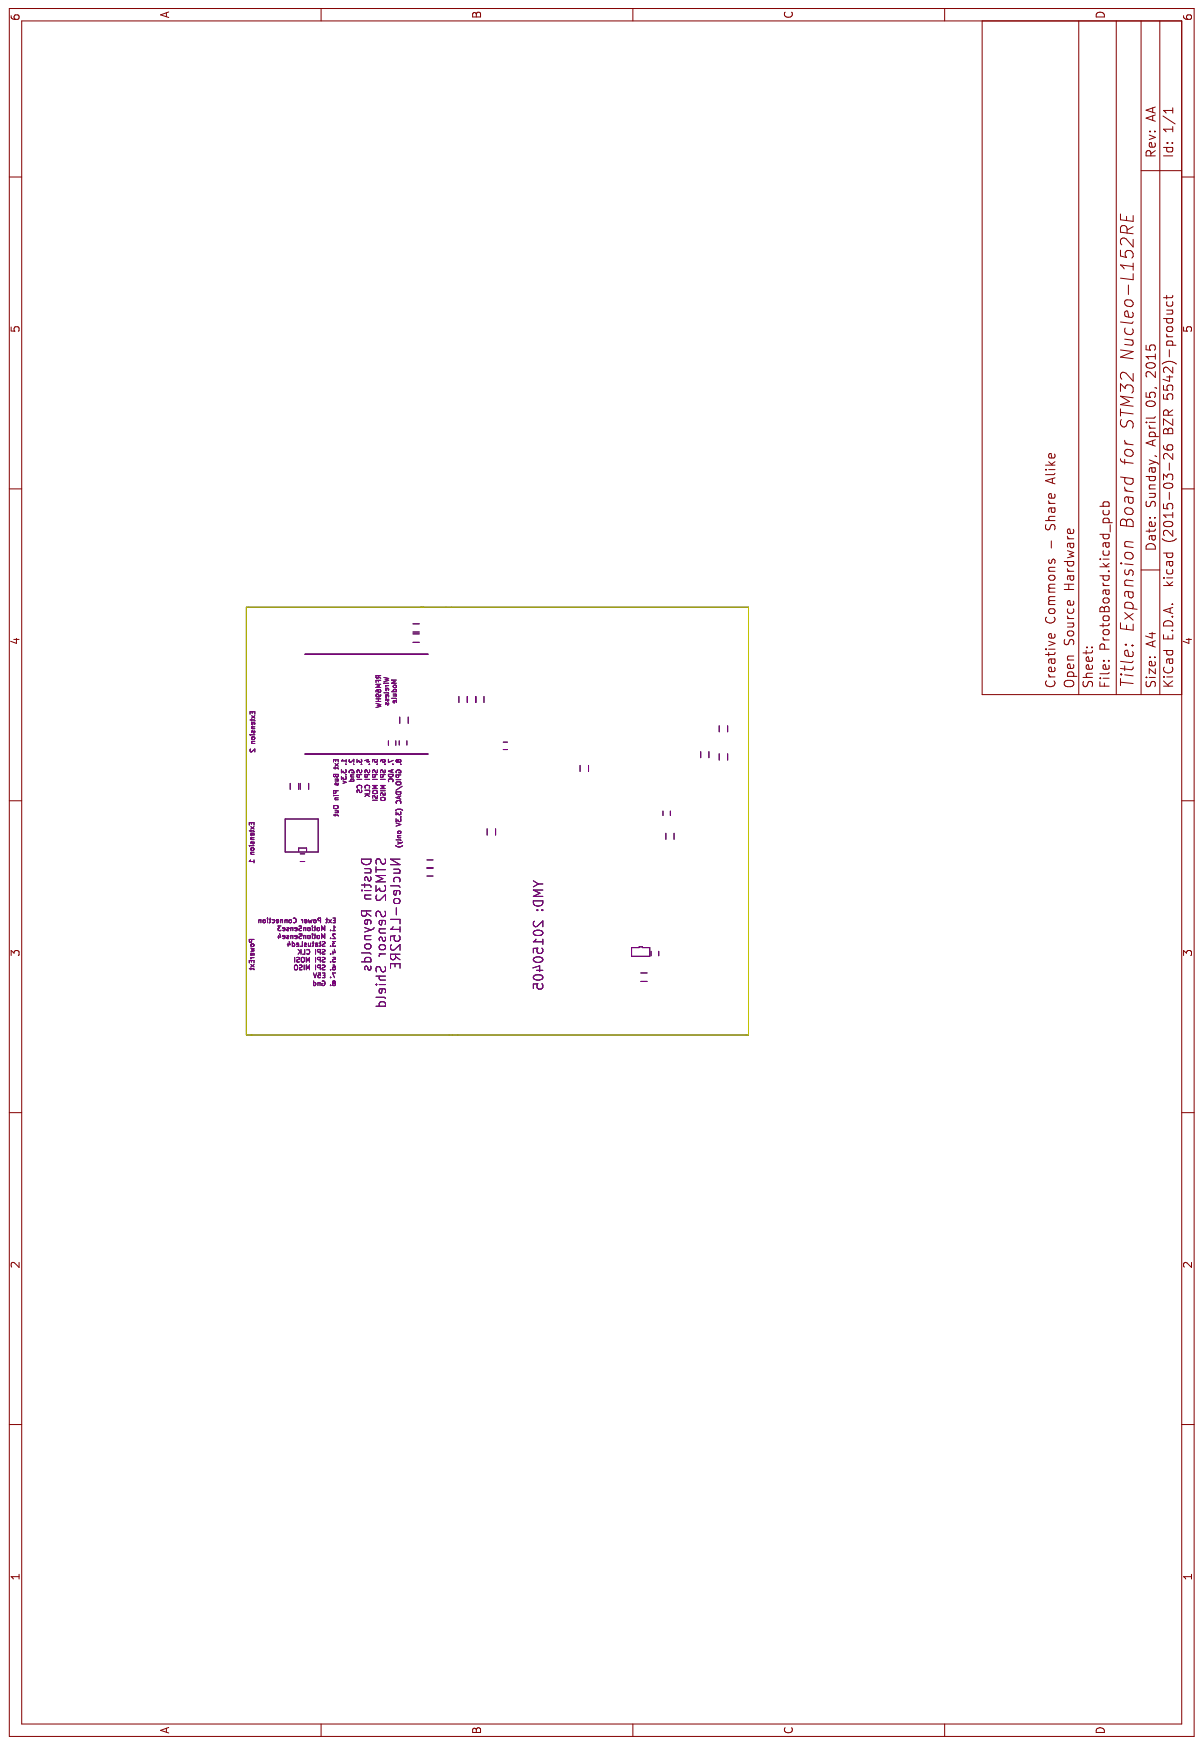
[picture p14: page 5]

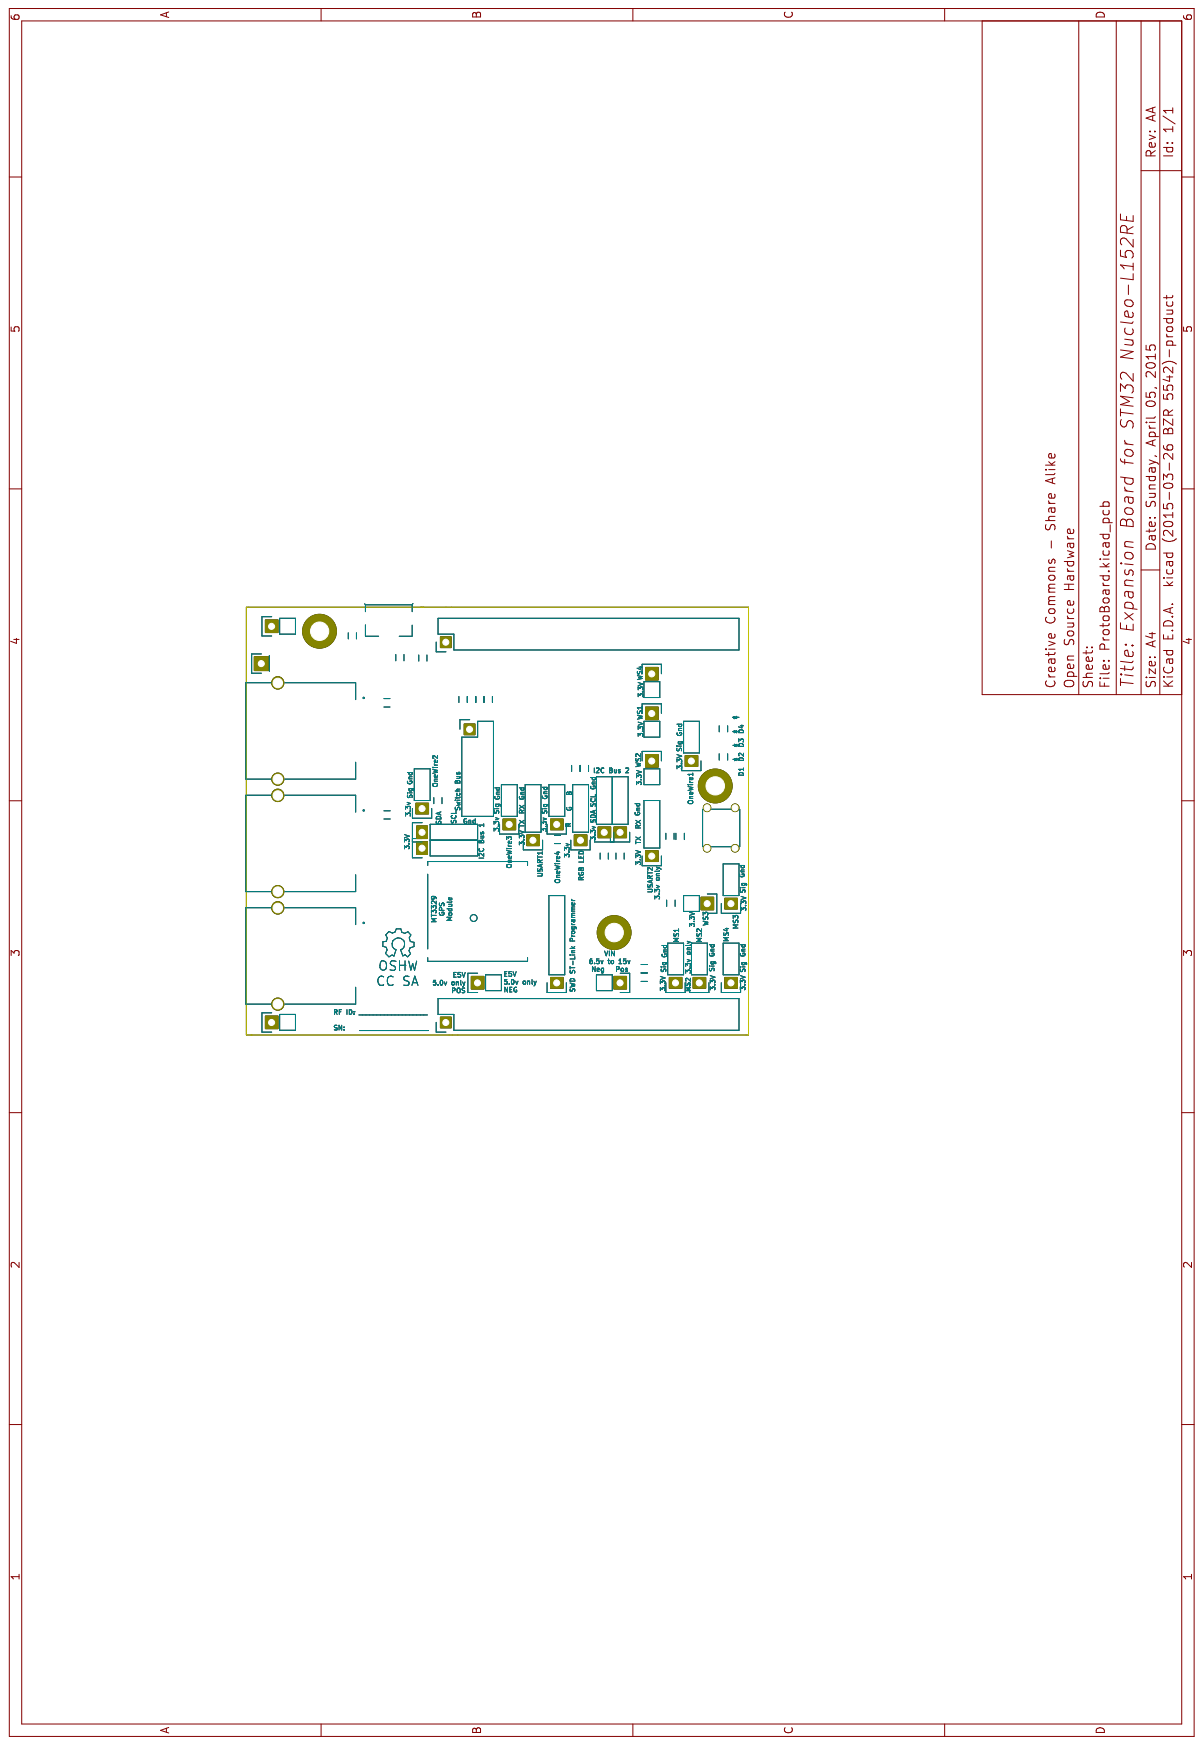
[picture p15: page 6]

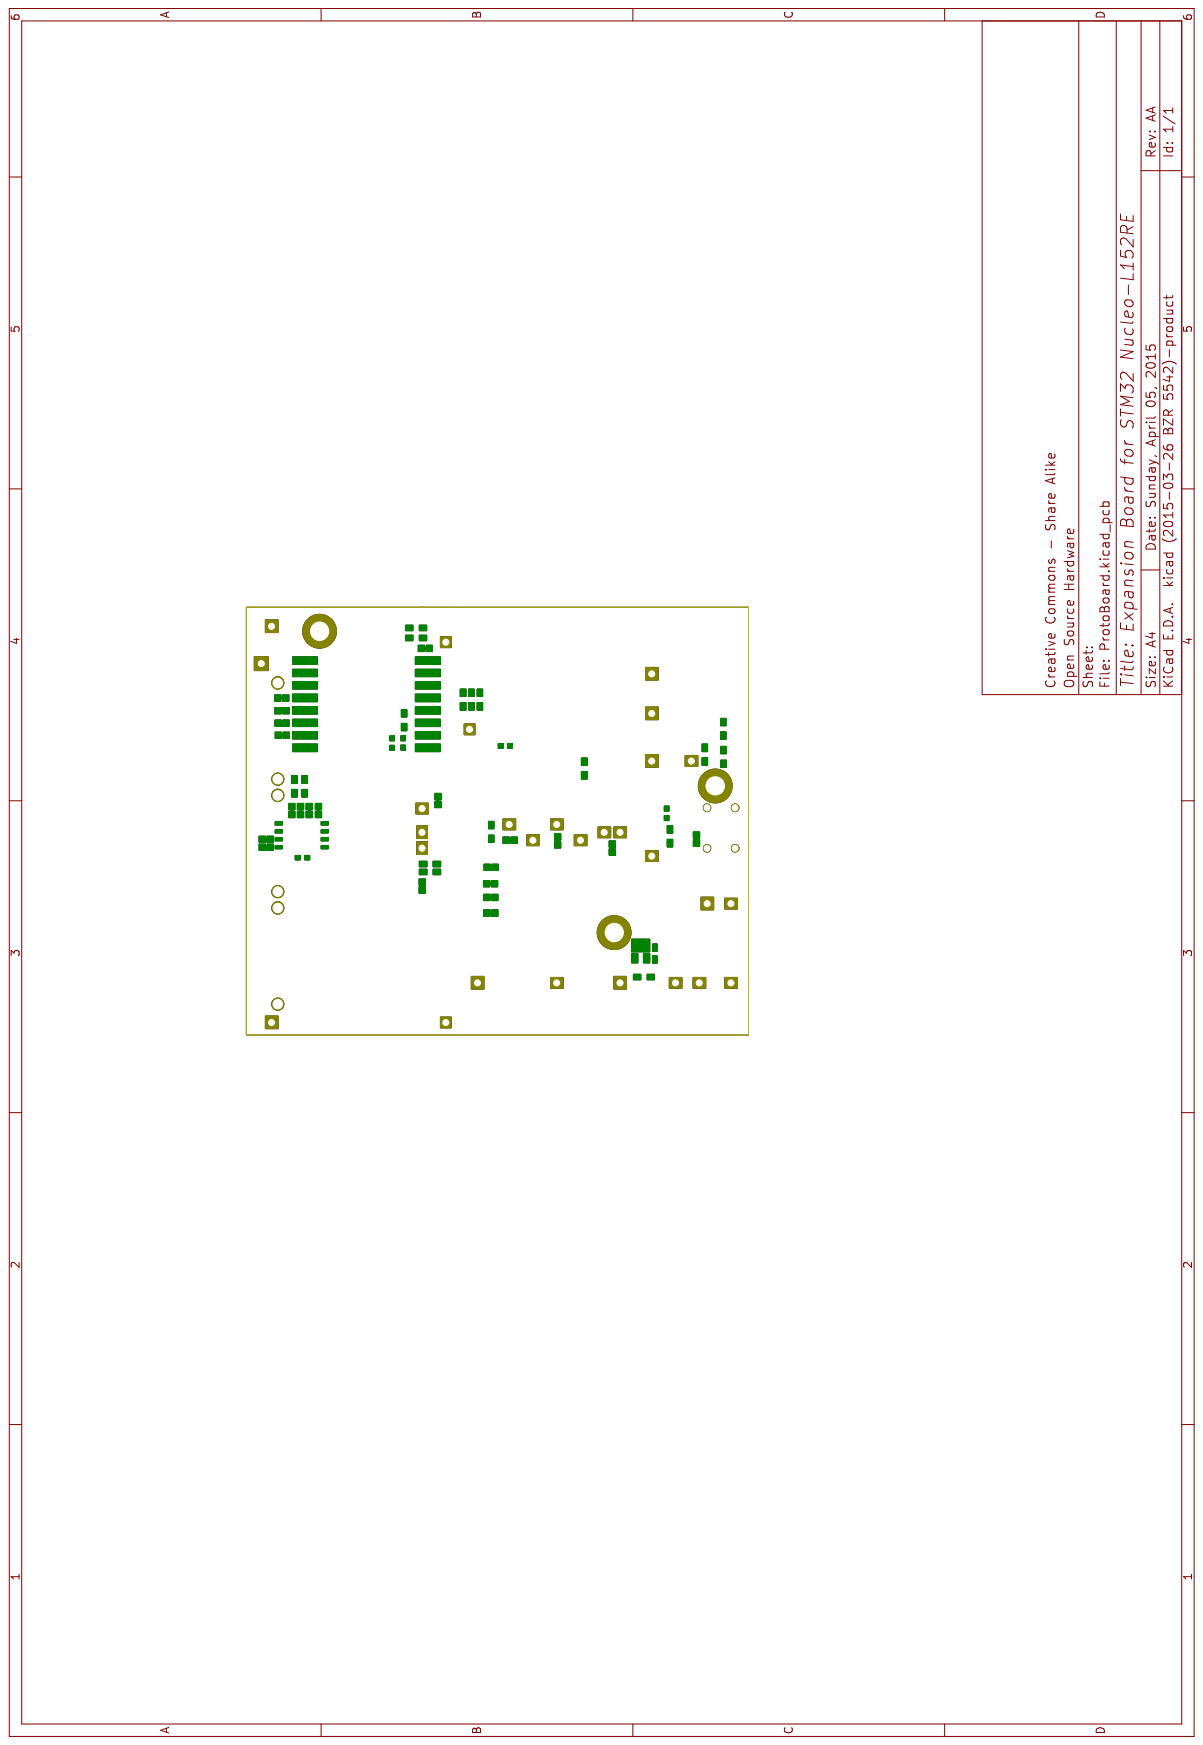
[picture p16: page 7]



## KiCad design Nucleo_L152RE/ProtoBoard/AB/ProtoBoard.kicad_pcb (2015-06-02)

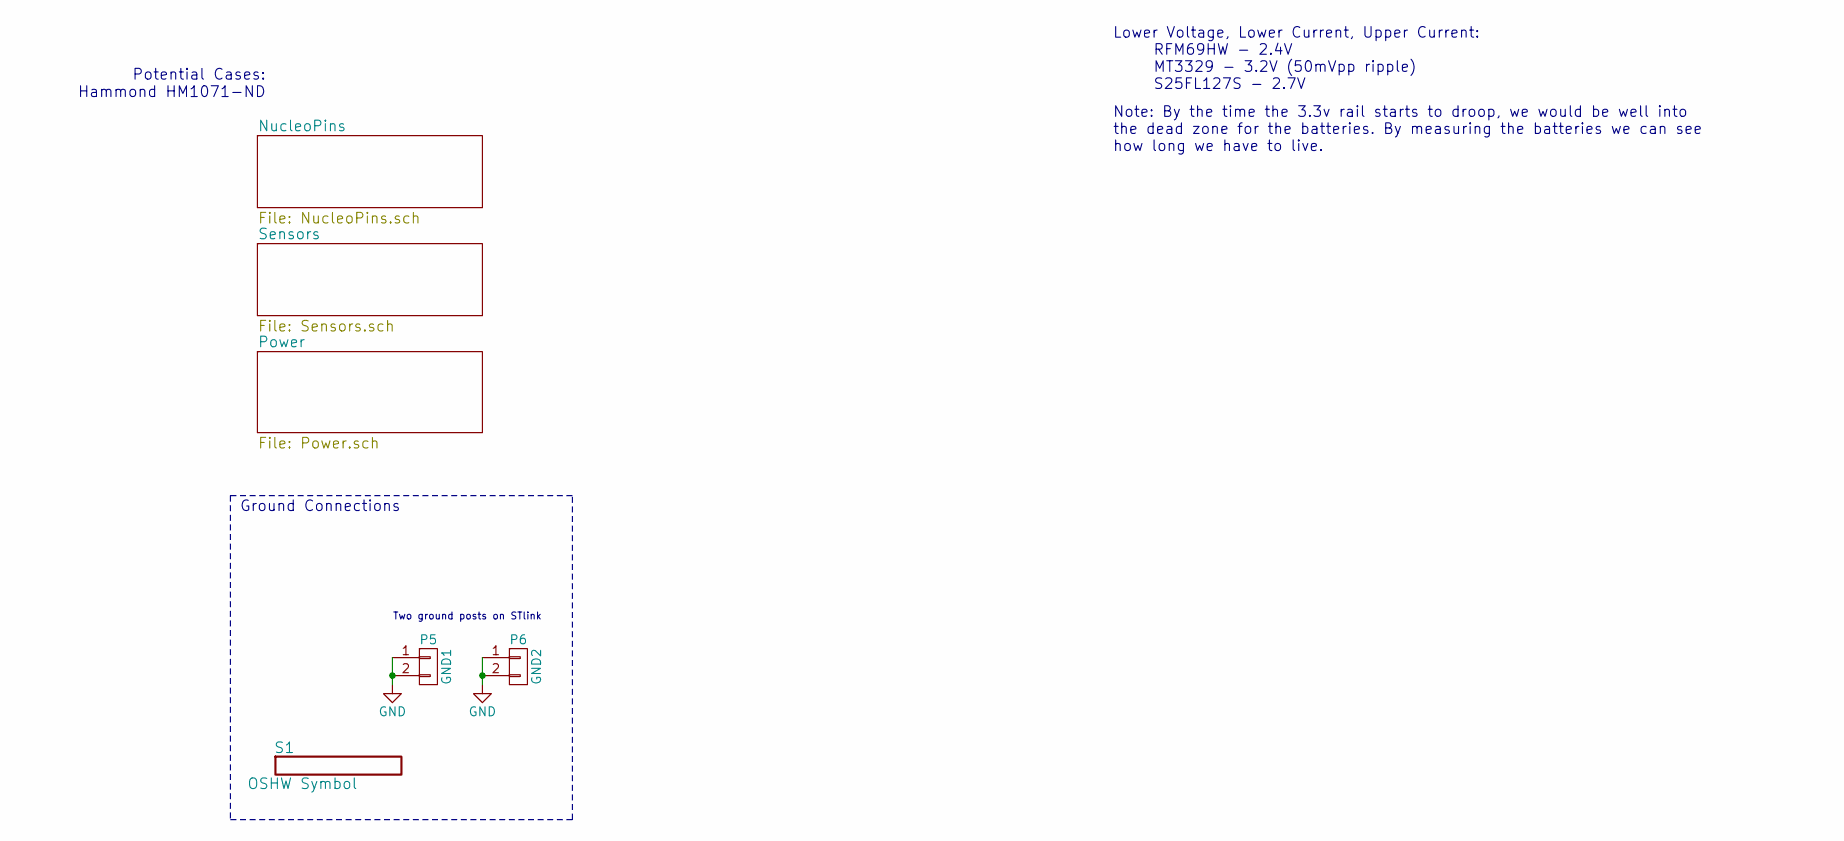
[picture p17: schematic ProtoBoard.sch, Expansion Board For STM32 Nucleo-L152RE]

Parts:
P5: GND1; Pin_Header_Straight_1x02
P6: GND2; Pin_Header_Straight_1x02
S1: OSHW Symbol; Symbol_OSHW-Logo_SilkScreen

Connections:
GND: P5.1, P5.2, P6.1, P6.2; also elsewhere on the board

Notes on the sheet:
Potential Cases: Hammond HM1071-ND
Ground Connections
Two ground posts on STlink
Lower Voltage, Lower Current, Upper Current: RFM69HW - 2.4V MT3329 - 3.2V (50mVpp ripple) S25FL127S - 2.7V
Note: By the time the 3.3v rail starts to droop, we would be well into the dead zone for the batteries. By measuring the batteries we can see how long we have to live.

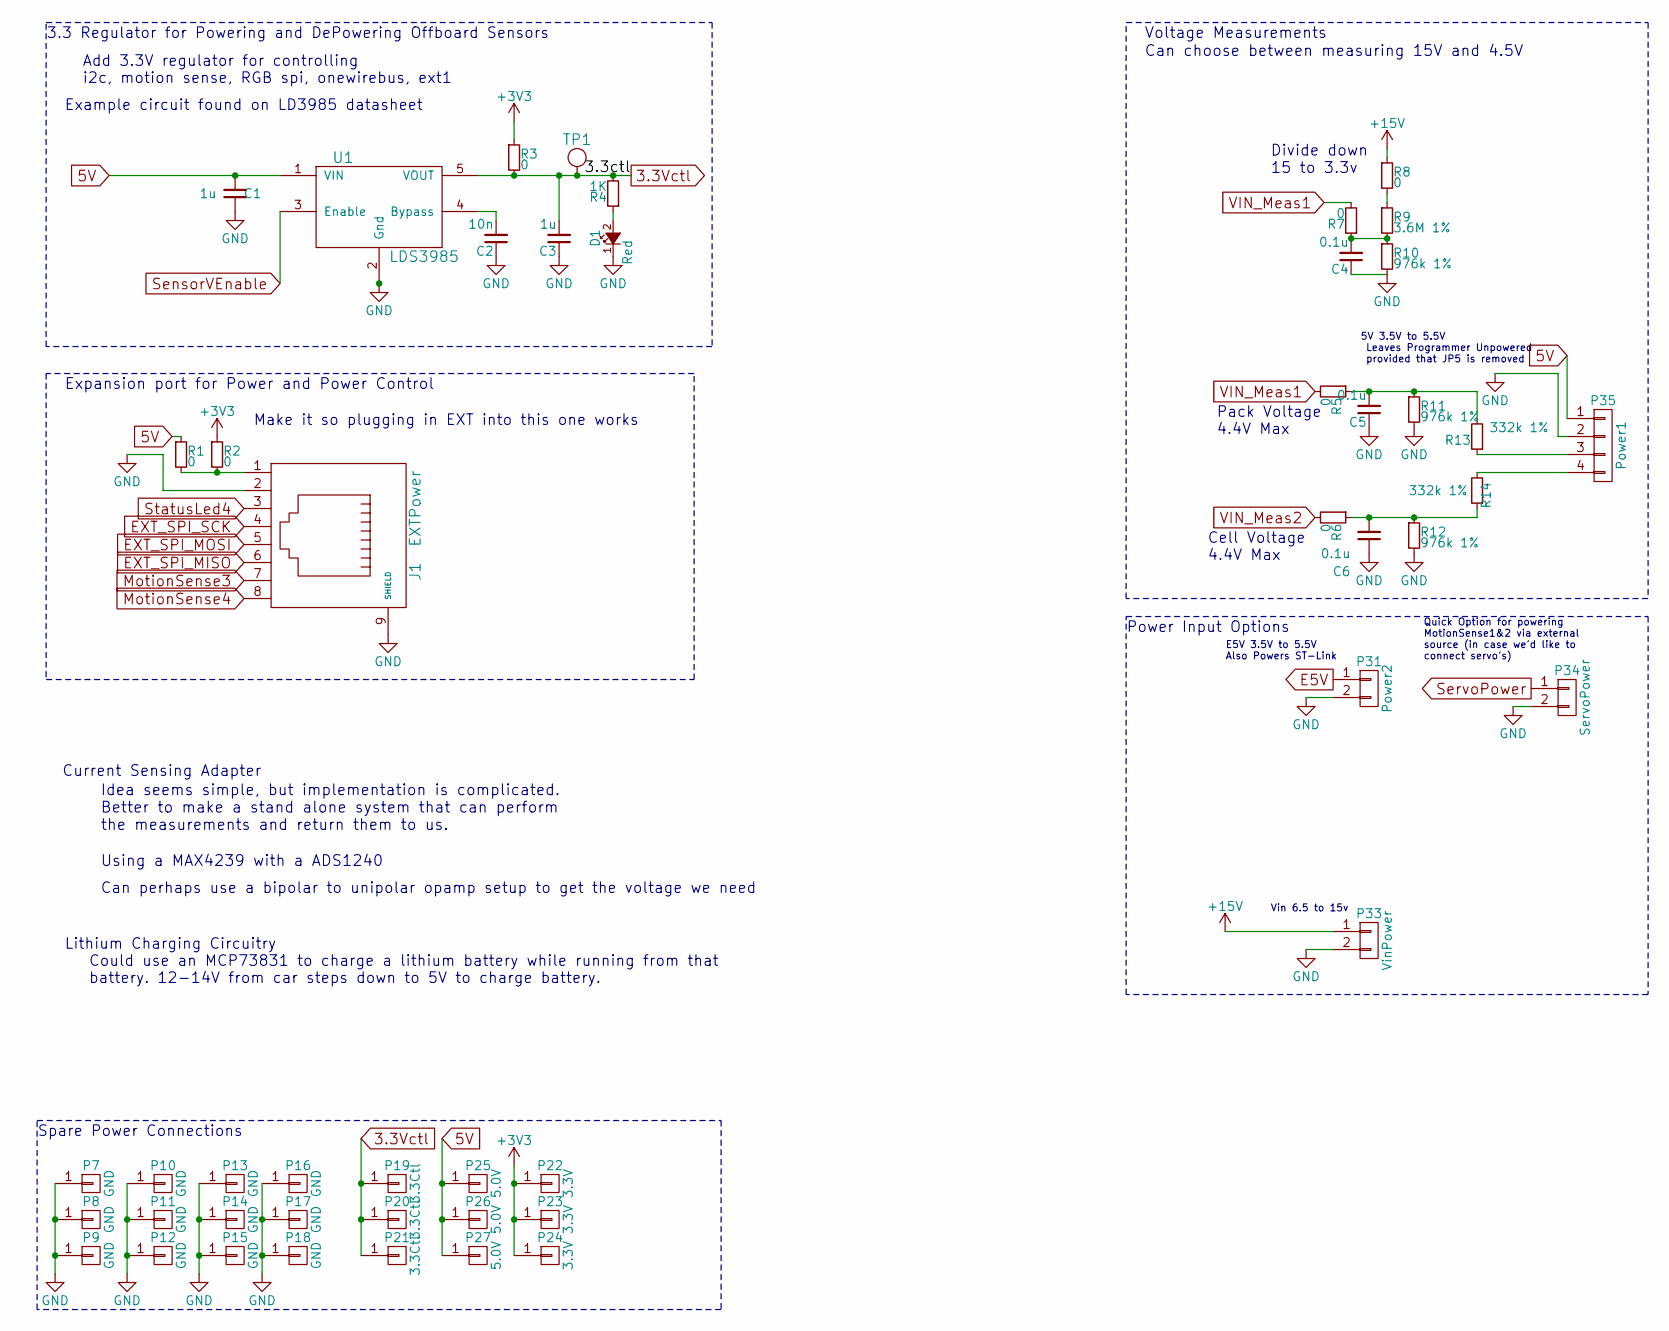
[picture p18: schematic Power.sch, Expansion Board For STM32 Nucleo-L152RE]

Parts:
C1, C3: 1u; C_0603_HandSoldering
C2: 10n; C_0603_HandSoldering
C4, C5, C6: 0.1u; C_0603_HandSoldering; Digikey Part Number 490-1532-1-ND
D1: Red; LED_0603_Standard; Digikey Part Number 160-1447-1-ND
J1: EXTPower; RJ45_SMD; Digikey Part Number RJLSE4238101TTR-ND
P7, P8, P9, P10, P11, P12, P13, P14, P15, P16, P17, P18: GND; Pin_Header_Straight_1x01
P19, P20, P21: 3.3Ctl; Pin_Header_Straight_1x01
P22, P23, P24: 3.3V; Pin_Header_Straight_1x01
P25, P26, P27: 5.0V; Pin_Header_Straight_1x01
P31: Power2; Pin_Header_Straight_1x02
P33: VinPower; Pin_Header_Straight_1x02
P34: ServoPower; Pin_Header_Straight_1x02
P35: Power1; Pin_Header_Straight_1x04
R1, R2, R3, R5, R6, R7, R8: 0; R_0603_HandSoldering; Digikey Part Number P0.0GCT-ND
R4: 1K; R_0603_HandSoldering; Digikey Part Number P1.0KGCT-ND
R9: 3.6M 1%; R_0603_HandSoldering
R10, R11, R12: 976k 1%; R_0603_HandSoldering
R13, R14: 332k 1%; R_0603_HandSoldering
TP1: tp; TestPoint_1mm
U1: LDS3985; SOT23-5L

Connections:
3.3Vctl: C3.2, P19.1, P20.1, P21.1, R3.2, R4.2, TP1.1, U1.5 (VOUT); also elsewhere on the board
5V: C1.2, P25.1, P26.1, P27.1, P35.1, R1.1, U1.1 (VIN); also elsewhere on the board
+3V3: P22.1, P23.1, P24.1, R2.1, R3.1; also elsewhere on the board
+15V: P33.1, R8.1; also elsewhere on the board
E5V: P31.1; also elsewhere on the board
EXT_SPI_MISO: J1.6; also elsewhere on the board
EXT_SPI_MOSI: J1.5; also elsewhere on the board
EXT_SPI_SCK: J1.4; also elsewhere on the board
GND: C1.1, C2.1, C3.1, C4.1, C5.1, C6.1, D1.1 (K), J1.2, J1.9 (SHIELD), P7.1, P8.1, P9.1, P10.1, P11.1, P12.1, P13.1, P14.1, P15.1, P16.1, P17.1, P18.1, P31.2, P33.2, P34.2, P35.2, R10.2, R11.2, R12.2, U1.2 (Gnd); also elsewhere on the board
MotionSense3: J1.7; also elsewhere on the board
MotionSense4: J1.8; also elsewhere on the board
unnamed: C2.2, U1.4 (Bypass)
unnamed: C4.2, R7.1, R9.2, R10.1
unnamed: C5.2, R5.1, R11.1, R13.2
unnamed: C6.2, R6.1, R12.1, R14.1
unnamed: D1.2 (A), R4.1
unnamed: J1.1, R1.2, R2.2
unnamed: P35.3, R13.1
unnamed: P35.4, R14.2
unnamed: R8.2, R9.1
SensorVEnable: U1.3 (Enable); also elsewhere on the board
ServoPower: P34.1; also elsewhere on the board
StatusLed4: J1.3; also elsewhere on the board
VIN_Meas1: R5.2, R7.2; also elsewhere on the board
VIN_Meas2: R6.2; also elsewhere on the board

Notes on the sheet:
Add 3.3V regulator for controlling i2c, motion sense, RGB spi, onewirebus, ext1
Voltage Measurements
Divide down 15 to 3.3v
Vin 6.5 to 15v
E5V 3.5V to 5.5V Also Powers ST-Link
Expansion port for Power and Power Control
Make it so plugging in EXT into this one works
5V 3.5V to 5.5V Leaves Programmer Unpowered provided that JP5 is removed
Cell Voltage 4.4V Max
Pack Voltage 4.4V Max
Can choose between measuring 15V and 4.5V
Current Sensing Adapter
Idea seems simple, but implementation is complicated. Better to make a stand alone system that can perform the measurements and return them to us.
Using a MAX4239 with a ADS1240
3.3 Regulator for Powering and DePowering Offboard Sensors
Power Input Options
Quick Option for powering MotionSense1&2 via external source (in case we'd like to connect servo's)
Lithium Charging Circuitry Could use an MCP73831 to charge a lithium battery while running from that battery. 12-14V from car steps down to 5V to charge battery.
Can perhaps use a bipolar to unipolar opamp setup to get the voltage we need
Spare Power Connections
Example circuit found on LD3985 datasheet

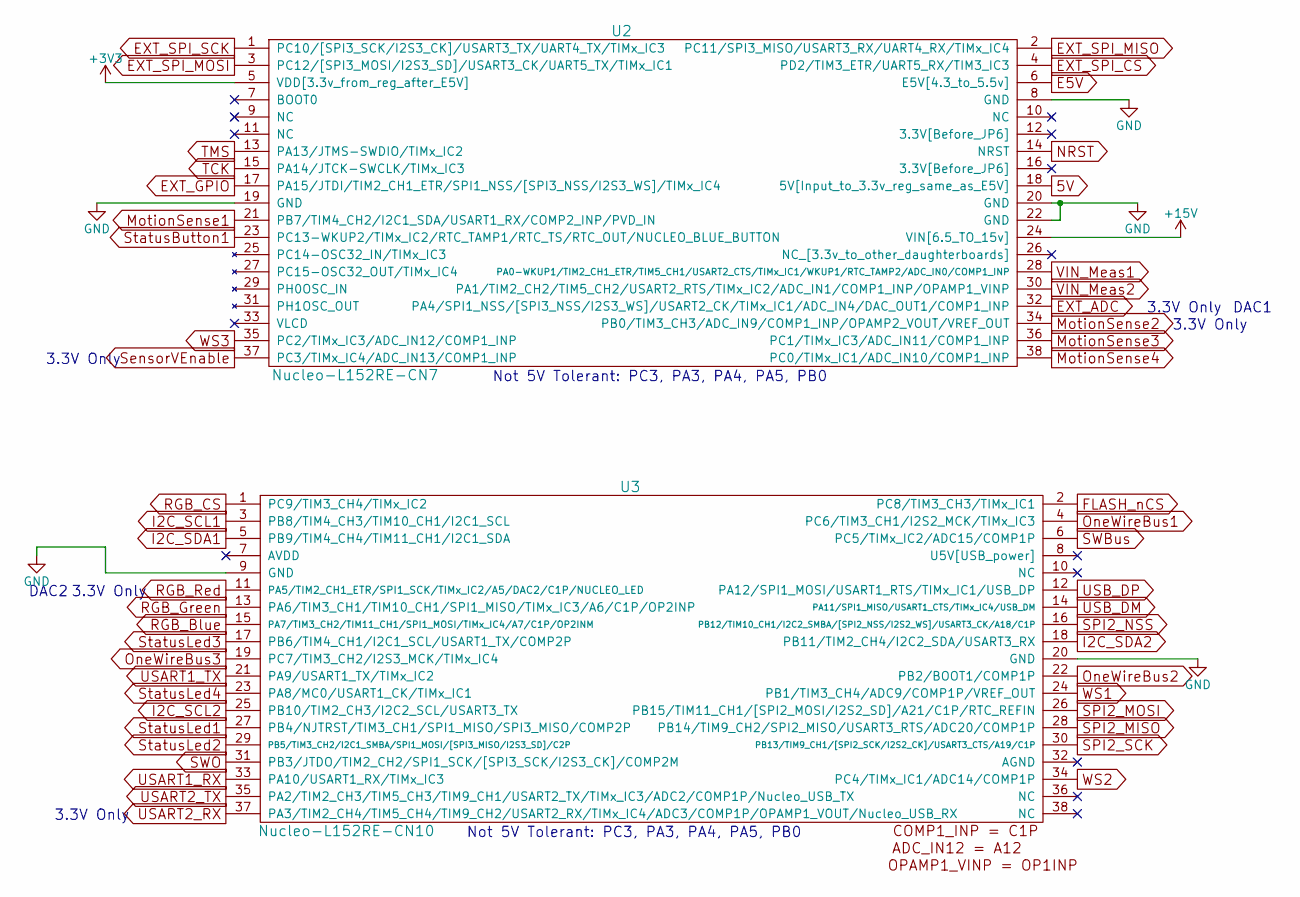
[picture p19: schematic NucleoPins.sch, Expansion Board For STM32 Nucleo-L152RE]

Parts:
U2: Nucleo-L152RE-CN7; Pin_Header_Straight_2x19; Digikey Part Number 497-14363-ND
U3: Nucleo-L152RE-CN10; Pin_Header_Straight_2x19

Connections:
5V: U2.18 (5V[Input_to_3.3v_reg_same_as_E5V]); also elsewhere on the board
+3V3: U2.5 (VDD[3.3v_from_reg_after_E5V]); also elsewhere on the board
+15V: U2.24 (VIN[6.5_TO_15v]); also elsewhere on the board
E5V: U2.6 (E5V[4.3_to_5.5v]); also elsewhere on the board
EXT_ADC: U2.32 (PA4/SPI1_NSS/[SPI3_NSS/I2S3_WS]/USART2_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); also elsewhere on the board
EXT_GPIO: U2.17 (PA15/JTDI/TIM2_CH1_ETR/SPI1_NSS/[SPI3_N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); also elsewhere on the board
EXT_SPI_CS: U2.4 (PD2/TIM3_ETR/UART5_RX/TIM3_IC3); also elsewhere on the board
EXT_SPI_MISO: U2.2 (PC11/SPI3_MISO/USART3_RX/UART4_RX/TIMx_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); also elsewhere on the board
EXT_SPI_MOSI: U2.3 (PC12/[SPI3_MOSI/I2S3_SD]/USART3_CK/UART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); also elsewhere on the board
EXT_SPI_SCK: U2.1 (PC10/[SPI3_SCK/I2S3_CK]/USART3_TX/UART4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); also elsewhere on the board
FLASH_nCS: U3.2 (PC8/TIM3_CH3/TIMx_IC1); also elsewhere on the board
GND: U2.8 (GND), U2.19 (GND), U2.20 (GND), U2.22 (GND), U3.9 (GND), U3.20 (GND); also elsewhere on the board
I2C_SCL1: U3.3 (PB8/TIM4_CH3/TIM10_CH1/I2C1_SCL); also elsewhere on the board
I2C_SCL2: U3.25 (PB10/TIM2_CH3/I2C2_SCL/USART3_TX); also elsewhere on the board
I2C_SDA1: U3.5 (PB9/TIM4_CH4/TIM11_CH1/I2C1_SDA); also elsewhere on the board
I2C_SDA2: U3.18 (PB11/TIM2_CH4/I2C2_SDA/USART3_RX); also elsewhere on the board
MotionSense1: U2.21 (PB7/TIM4_CH2/I2C1_SDA/USART1_RX/COMP2_I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); also elsewhere on the board
MotionSense2: U2.34 (PB0/TIM3_CH3/ADC_IN9/COMP1_INP/OPAMP2_V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); also elsewhere on the board
MotionSense3: U2.36 (PC1/TIMx_IC3/ADC_IN11/COMP1_INP); also elsewhere on the board
MotionSense4: U2.38 (PC0/TIMx_IC1/ADC_IN10/COMP1_INP); also elsewhere on the board
NRST: U2.14 (NRST); also elsewhere on the board
OneWireBus1: U3.4 (PC6/TIM3_CH1/I2S2_MCK/TIMx_IC3); also elsewhere on the board
OneWireBus2: U3.22 (PB2/BOOT1/COMP1P); also elsewhere on the board
OneWireBus3: U3.19 (PC7/TIM3_CH2/I2S3_MCK/TIMx_IC4); also elsewhere on the board
RGB_Blue: U3.15 (PA7/TIM3_CH2/TIM11_CH1/SPI1_MOSI/TIMx_I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); also elsewhere on the board
RGB_CS: U3.1 (PC9/TIM3_CH4/TIMx_IC2); also elsewhere on the board
RGB_Green: U3.13 (PA6/TIM3_CH1/TIM10_CH1/SPI1_MISO/TIMx_I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); also elsewhere on the board
RGB_Red: U3.11 (PA5/TIM2_CH1_ETR/SPI1_SCK/TIMx_IC2/A5/D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); also elsewhere on the board
SPI2_MISO: U3.28 (PB14/TIM9_CH2/SPI2_MISO/USART3_RTS/ADC2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); also elsewhere on the board
SPI2_MOSI: U3.26 (PB15/TIM11_CH1/[SPI2_MOSI/I2S2_SD]/A21/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); also elsewhere on the board
SPI2_NSS: U3.16 (PB12/TIM10_CH1/I2C2_SMBA/[SPI2_NSS/I2S2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); also elsewhere on the board
SPI2_SCK: U3.30 (PB13/TIM9_CH1/[SPI2_SCK/I2S2_CK]/USART3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); also elsewhere on the board
SWBus: U3.6 (PC5/TIMx_IC2/ADC15/COMP1P); also elsewhere on the board
SWO: U3.31 (PB3/JTDO/TIM2_CH2/SPI1_SCK/[SPI3_SCK/I2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); also elsewhere on the board
SensorVEnable: U2.37 (PC3/TIMx_IC4/ADC_IN13/COMP1_INP); also elsewhere on the board
StatusButton1: U2.23 (PC13-WKUP2/TIMx_IC2/RTC_TAMP1/RTC_TS/RT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); also elsewhere on the board
StatusLed1: U3.27 (PB4/NJTRST/TIM3_CH1/SPI1_MISO/SPI3_MISO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); also elsewhere on the board
StatusLed2: U3.29 (PB5/TIM3_CH2/I2C1_SMBA/SPI1_MOSI/[SPI3_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); also elsewhere on the board
StatusLed3: U3.17 (PB6/TIM4_CH1/I2C1_SCL/USART1_TX/COMP2P); also elsewhere on the board
StatusLed4: U3.23 (PA8/MC0/USART1_CK/TIMx_IC1); also elsewhere on the board
TCK: U2.15 (PA14/JTCK-SWCLK/TIMx_IC3); also elsewhere on the board
TMS: U2.13 (PA13/JTMS-SWDIO/TIMx_IC2); also elsewhere on the board
USART1_RX: U3.33 (PA10/USART1_RX/TIMx_IC3); also elsewhere on the board
USART1_TX: U3.21 (PA9/USART1_TX/TIMx_IC2); also elsewhere on the board
USART2_RX: U3.37 (PA3/TIM2_CH4/TIM5_CH4/TIM9_CH2/USART2_R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); also elsewhere on the board
USART2_TX: U3.35 (PA2/TIM2_CH3/TIM5_CH3/TIM9_CH1/USART2_T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); also elsewhere on the board
USB_DM: U3.14 (PA11/SPI1_MISO/USART1_CTS/TIMx_IC4/USB_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); also elsewhere on the board
USB_DP: U3.12 (PA12/SPI1_MOSI/USART1_RTS/TIMx_IC1/USB_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); also elsewhere on the board
VIN_Meas1: U2.28 (PA0-WKUP1/TIM2_CH1_ETR/TIM5_CH1/USART2_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); also elsewhere on the board
VIN_Meas2: U2.30 (PA1/TIM2_CH2/TIM5_CH2/USART2_RTS/TIMx_I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); also elsewhere on the board
WS1: U3.24 (PB1/TIM3_CH4/ADC9/COMP1P/VREF_OUT); also elsewhere on the board
WS2: U3.34 (PC4/TIMx_IC1/ADC14/COMP1P); also elsewhere on the board
WS3: U2.35 (PC2/TIMx_IC3/ADC_IN12/COMP1_INP); also elsewhere on the board

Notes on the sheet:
Not 5V Tolerant: PC3, PA3, PA4, PA5, PB0
DAC2
DAC1
3.3V Only

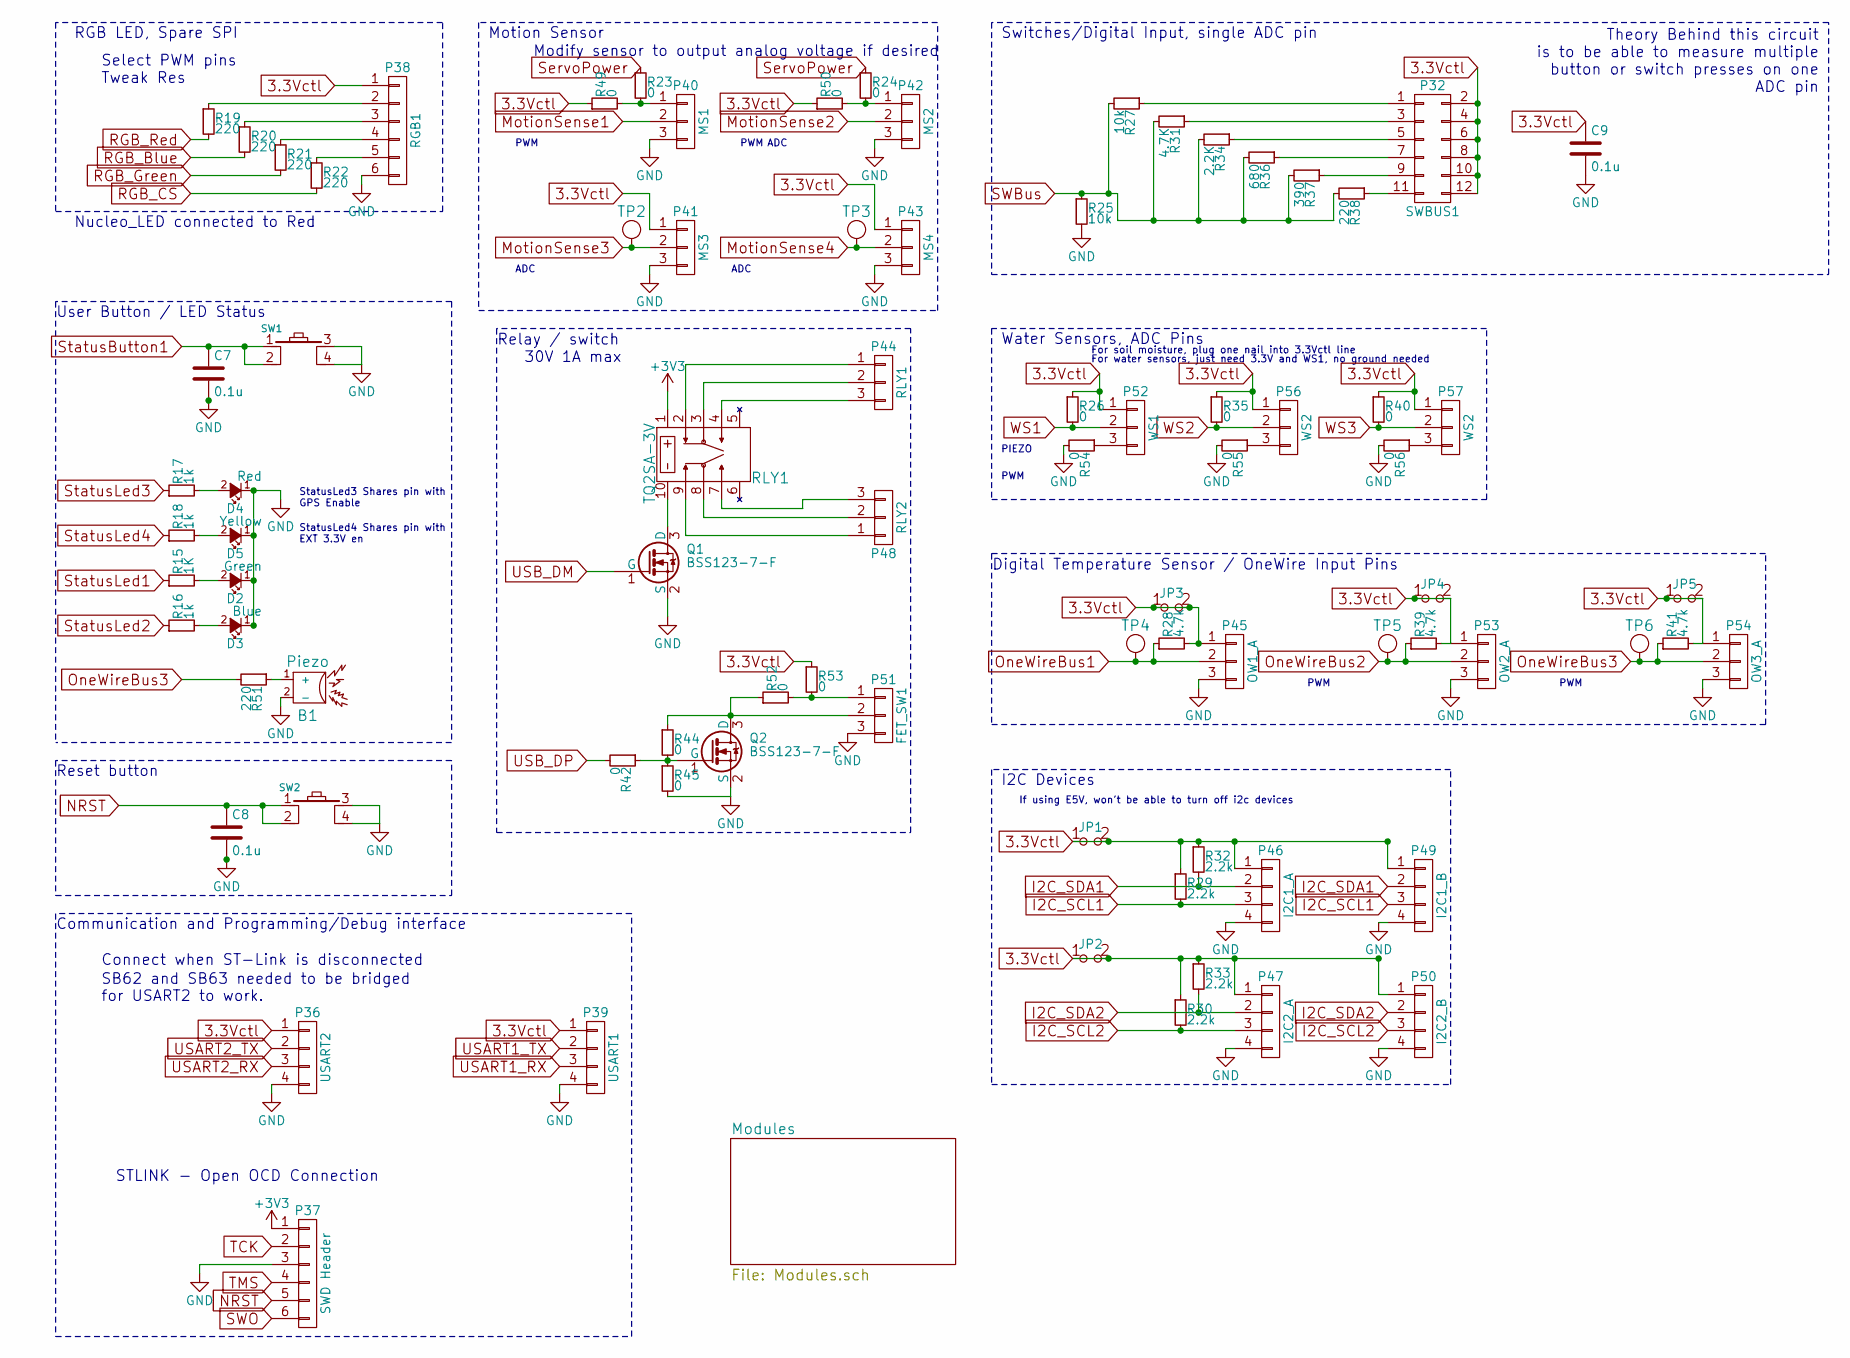
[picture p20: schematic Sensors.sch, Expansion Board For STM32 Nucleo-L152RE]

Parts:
B1: Piezo; Piezo_12mm
C7, C8, C9: 0.1u; C_0603; Digikey Part Number 490-1532-1-ND
D2: Green; LED_0603_Standard; Digikey Part Number 160-1446-1-ND
D3: Blue; LED_0603_Standard; Digikey Part Number 160-1647-1-ND
D4: Red; LED_0603_Standard; Digikey Part Number 160-1447-1-ND
D5: Yellow; LED_0603_Standard; Digikey Part Number 160-1448-1-ND
JP1, JP2, JP3, JP4, JP5: Jumper_NC_Small; SB_NO_Smaller
P32: SWBUS1; Pin_Header_Straight_2x06
P36: USART2; Pin_Header_Straight_1x04
P37: SWD Header; Pin_Header_Straight_1x06
P38: RGB1; Pin_Header_Straight_1x06
P39: USART1; Pin_Header_Straight_1x04
P40: MS1; Pin_Header_Straight_1x03
P41: MS3; Pin_Header_Straight_1x03
P42: MS2; Pin_Header_Straight_1x03
P43: MS4; Pin_Header_Straight_1x03
P44: RLY1; Pin_Header_Straight_1x03
P45: OW1_A; Pin_Header_Straight_1x03
P46: I2C1_A; Pin_Header_Straight_1x04
P47: I2C2_A; Pin_Header_Straight_1x04
P48: RLY2; Pin_Header_Straight_1x03
P49: I2C1_B; Pin_Header_Straight_1x04
P50: I2C2_B; Pin_Header_Straight_1x04
P51: FET_SW1; Pin_Header_Straight_1x03
P52: WS1; Pin_Header_Straight_1x03
P53: OW2_A; Pin_Header_Straight_1x03
P54: OW3_A; Pin_Header_Straight_1x03
P56, P57: WS2; Pin_Header_Straight_1x03
Q1, Q2: BSS123-7-F; SOT23-3
R15: 1K; R_0603_HandSoldering; Digikey Part Number P1.0KGCT-ND
R16, R17, R18: 1k; R_0603_HandSoldering; Digikey Part Number P1.0KGCT-ND
R19, R20, R21, R22, R38, R51: 220; R_0603_HandSoldering; Digikey Part Number P220GCT-ND
R23, R24, R26, R35, R40, R42, R44, R45, R49, R50, R52, R53, R54, R55, R56: 0; R_0603_HandSoldering; Digikey Part Number P0.0GCT-ND
R25, R27: 10k; R_0603_HandSoldering; Digikey Part Number P10KGCT-ND
R28, R39, R41: 4.7k; R_0603_HandSoldering; Digikey Part Number P4.7KGCT-ND
R29, R30, R32, R33: 2.2k; R_0603_HandSoldering; Digikey Part Number P2.2KGCT-ND
R31: 4.7K; R_0603_HandSoldering; Digikey Part Number P4.7KGCT-ND
R34: 2.2K; R_0603_HandSoldering; Digikey Part Number P2.2KGCT-ND
R36: 680; R_0603_HandSoldering; Digikey Part Number P680GCT-ND
R37: 390; R_0603_HandSoldering; Digikey Part Number P390GCT-ND
RLY1: TQ2SA-3V; Relay_SMD
SW1: MomentarySwitch; Tact_switch; Digikey Part Number 450-1650-ND
SW2: ResetSwitch; Tact_switch; Digikey Part Number 450-1650-ND
TP2, TP3, TP4, TP5, TP6: tp; TestPoint_1mm

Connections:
3.3Vctl: C9.1, JP1.1, JP1.2, JP2.1, JP2.2, JP3.1, JP3.2, JP4.1, JP4.2, JP5.1, JP5.2, P32.2, P32.4, P32.6, P32.8, P32.10, P32.12, P36.1, P38.1, P39.1, P41.1, P43.1, P45.1, P46.1, P47.1, P49.1, P50.1, P52.1, P53.1, P54.1, P56.1, P57.1, R26.1, R28.2, R29.1, R30.1, R32.1, R33.1, R35.1, R39.2, R40.1, R41.2, R49.1, R50.1, R53.1; also elsewhere on the board
+3V3: P37.1, RLY1.1; also elsewhere on the board
GND: B1.2 (-), C7.2, C8.2, C9.2, D2.1 (K), D3.1 (K), D4.1 (K), D5.1 (K), P36.4, P37.3, P38.6, P39.4, P40.3, P41.3, P42.3, P43.3, P45.3, P46.4, P47.4, P49.4, P50.4, P51.3, P53.3, P54.3, Q1.2 (S), Q2.2 (S), R25.2, R45.2, R54.2, R55.2, R56.2, SW1.3, SW1.4, SW2.3, SW2.4; also elsewhere on the board
I2C_SCL1: P46.3, P49.3, R29.2; also elsewhere on the board
I2C_SCL2: P47.3, P50.3, R30.2; also elsewhere on the board
I2C_SDA1: P46.2, P49.2, R32.2; also elsewhere on the board
I2C_SDA2: P47.2, P50.2, R33.2; also elsewhere on the board
MotionSense1: P40.2; also elsewhere on the board
MotionSense2: P42.2; also elsewhere on the board
MotionSense3: P41.2, TP2.1; also elsewhere on the board
MotionSense4: P43.2, TP3.1; also elsewhere on the board
NRST: C8.1, P37.5, SW2.1, SW2.2; also elsewhere on the board
unnamed: B1.1 (+), R51.1
unnamed: D2.2 (A), R15.2
unnamed: D3.2 (A), R16.2
unnamed: D4.2 (A), R17.2
unnamed: D5.2 (A), R18.2
unnamed: P32.1, R27.1
unnamed: P32.3, R31.1
unnamed: P32.5, R34.1
unnamed: P32.7, R36.1
unnamed: P32.9, R37.1
unnamed: P32.11, R38.1
unnamed: P38.2, R19.1
unnamed: P38.3, R20.1
unnamed: P38.4, R21.1
unnamed: P38.5, R22.1
unnamed: P40.1, R23.2, R49.2
unnamed: P42.1, R24.2, R50.2
unnamed: P44.1, RLY1.2
unnamed: P44.2, RLY1.3
unnamed: P44.3, RLY1.4
unnamed: P48.1, RLY1.9
unnamed: P48.2, RLY1.8
unnamed: P48.3, RLY1.7
unnamed: P51.1, R52.2, R53.2
unnamed: P51.2, Q2.3 (D), R44.1, R52.1
unnamed: P52.3, R54.1
unnamed: P56.3, R55.1
unnamed: P57.3, R56.1
unnamed: Q1.3 (D), RLY1.10
unnamed: Q2.1 (G), R42.1, R44.2, R45.1
OneWireBus1: P45.2, R28.1, TP4.1; also elsewhere on the board
OneWireBus2: P53.2, R39.1, TP5.1; also elsewhere on the board
OneWireBus3: P54.2, R41.1, R51.2, TP6.1; also elsewhere on the board
RGB_Blue: R20.2; also elsewhere on the board
RGB_CS: R22.2; also elsewhere on the board
RGB_Green: R21.2; also elsewhere on the board
RGB_Red: R19.2; also elsewhere on the board
SWBus: R25.1, R27.2, R31.2, R34.2, R36.2, R37.2, R38.2; also elsewhere on the board
SWO: P37.6; also elsewhere on the board
ServoPower: R23.1, R24.1; also elsewhere on the board
StatusButton1: C7.1, SW1.1, SW1.2; also elsewhere on the board
StatusLed1: R15.1; also elsewhere on the board
StatusLed2: R16.1; also elsewhere on the board
StatusLed3: R17.1; also elsewhere on the board
StatusLed4: R18.1; also elsewhere on the board
TCK: P37.2; also elsewhere on the board
TMS: P37.4; also elsewhere on the board
USART1_RX: P39.3; also elsewhere on the board
USART1_TX: P39.2; also elsewhere on the board
USART2_RX: P36.3; also elsewhere on the board
USART2_TX: P36.2; also elsewhere on the board
USB_DM: Q1.1 (G); also elsewhere on the board
USB_DP: R42.2; also elsewhere on the board
WS1: P52.2, R26.2; also elsewhere on the board
WS2: P56.2, R35.2; also elsewhere on the board
WS3: P57.2, R40.2; also elsewhere on the board

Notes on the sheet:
Switches/Digital Input, single ADC pin
Water Sensors, ADC Pins
Digital Temperature Sensor / OneWire Input Pins
Motion Sensor
Theory Behind this circuit is to be able to measure multiple button or switch presses on one ADC pin
If using E5V, won't be able to turn off i2c devices
RGB LED, Spare SPI
Select PWM pins Tweak Res
I2C Devices
PWM
StatusLed3 Shares pin with GPS Enable
StatusLed4 Shares pin with EXT 3.3V en
Modify sensor to output analog voltage if desired
Connect when ST-Link is disconnected
STLINK - Open OCD Connection
SB62 and SB63 needed to be bridged for USART2 to work.
Communication and Programming/Debug interface
User Button / LED Status
Reset button
PIEZO
ADC
For soil moisture, plug one nail into 3.3Vctl line
For water sensors, just need 3.3V and WS1, no ground needed
Relay / switch
Nucleo_LED connected to Red
30V 1A max

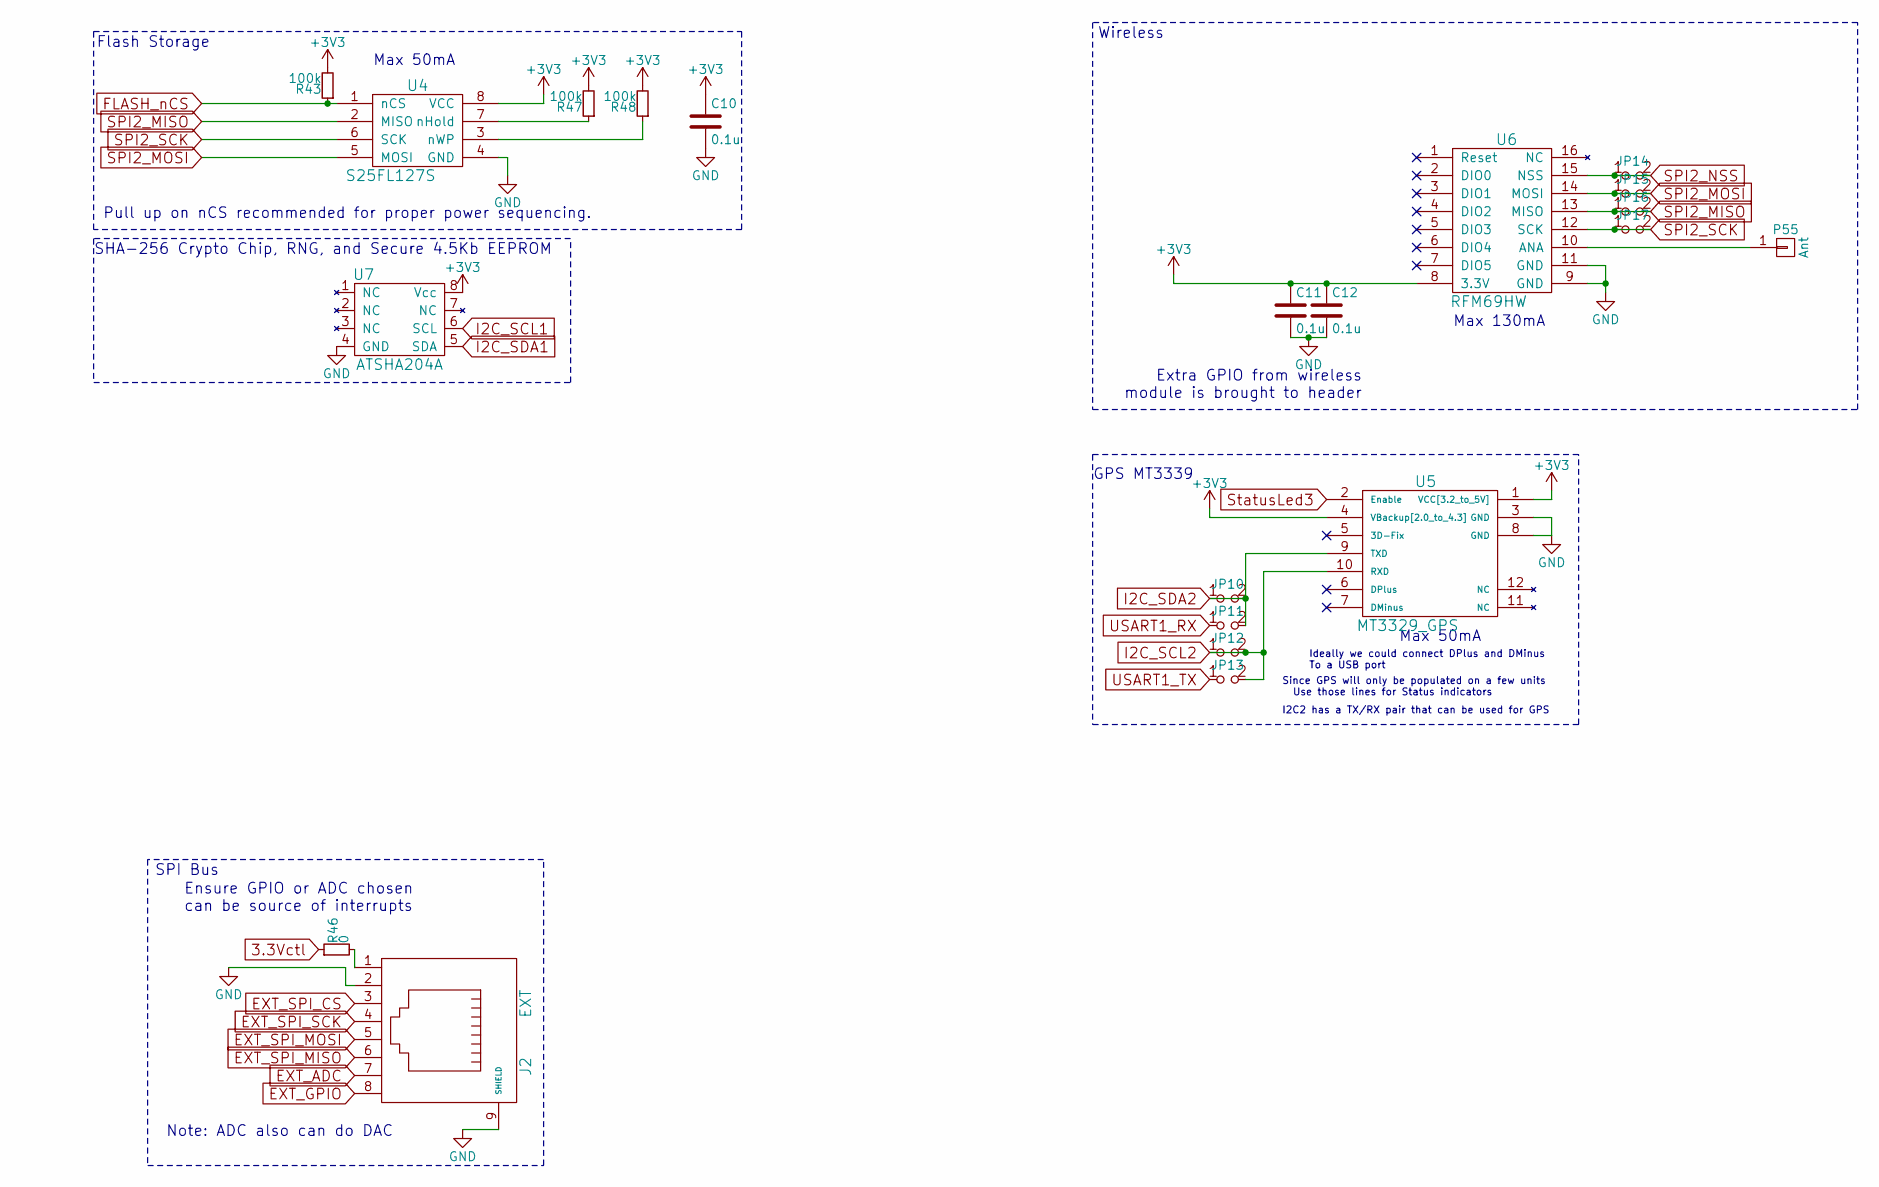
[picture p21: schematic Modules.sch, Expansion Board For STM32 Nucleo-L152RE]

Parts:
C10, C11, C12: 0.1u; C_0603; Digikey Part Number 490-1532-1-ND
J2: EXT; RJ45_SMD; Digikey Part Number RJLSE4238101TTR-ND
JP10, JP12, JP14, JP15, JP16, JP17: Jumper_NC_Small; SB_NO_Smaller
JP11, JP13: Jumper_NO_Small; SB_NO_Smaller
P55: Ant; Antenna_1pin
R43, R47, R48: 100k; R_0603_HandSoldering; Digikey Part Number RMCF0603FT100KTR-ND
R46: 0; R_0603_HandSoldering; Digikey Part Number P0.0GCT-ND
U4: S25FL127S; SOIC-8-FLASH; Digikey Part Number 1274-1045-ND
U5: MT3329_GPS; MT3329_LessPins
U6: RFM69HW; RFM69HW_LessPins
U7: ATSHA204A; 8-SOIC-JEDEC_MS-012AA

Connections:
3.3Vctl: R46.1; also elsewhere on the board
+3V3: C10.1, C11.1, C12.1, R43.2, R47.2, R48.2, U4.8 (VCC), U5.1 (VCC[3.2_to_5V]), U5.4 (VBackup[2.0_to_4.3]), U6.8 (3.3V), U7.8 (Vcc); also elsewhere on the board
EXT_ADC: J2.7; also elsewhere on the board
EXT_GPIO: J2.8; also elsewhere on the board
EXT_SPI_CS: J2.3; also elsewhere on the board
EXT_SPI_MISO: J2.6; also elsewhere on the board
EXT_SPI_MOSI: J2.5; also elsewhere on the board
EXT_SPI_SCK: J2.4; also elsewhere on the board
FLASH_nCS: R43.1, U4.1 (nCS); also elsewhere on the board
GND: C10.2, C11.2, C12.2, J2.2, J2.9 (SHIELD), U4.4 (GND), U5.3 (GND), U5.8 (GND), U6.9 (GND), U6.11 (GND), U7.4 (GND); also elsewhere on the board
I2C_SCL1: U7.6 (SCL); also elsewhere on the board
I2C_SCL2: JP12.1, JP12.2, JP13.2, U5.10 (RXD); also elsewhere on the board
I2C_SDA1: U7.5 (SDA); also elsewhere on the board
I2C_SDA2: JP10.1, JP10.2, JP11.2, U5.9 (TXD); also elsewhere on the board
unnamed: J2.1, R46.2
unnamed: P55.1, U6.10 (ANA)
unnamed: R47.1, U4.7 (nHold)
unnamed: R48.1, U4.3 (nWP)
SPI2_MISO: JP16.1, JP16.2, U4.2 (MISO), U6.13 (MISO); also elsewhere on the board
SPI2_MOSI: JP15.1, JP15.2, U4.5 (MOSI), U6.14 (MOSI); also elsewhere on the board
SPI2_NSS: JP14.1, JP14.2, U6.15 (NSS); also elsewhere on the board
SPI2_SCK: JP17.1, JP17.2, U4.6 (SCK), U6.12 (SCK); also elsewhere on the board
StatusLed3: U5.2 (Enable); also elsewhere on the board
USART1_RX: JP11.1; also elsewhere on the board
USART1_TX: JP13.1; also elsewhere on the board

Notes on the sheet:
Flash Storage
Max 50mA
Wireless
Extra GPIO from wireless module is brought to header
Max 130mA
SPI Bus
Ensure GPIO or ADC chosen can be source of interrupts
Note: ADC also can do DAC
Ideally we could connect DPlus and DMinus To a USB port
GPS MT3339
Since GPS will only be populated on a few units Use those lines for Status indicators
I2C2 has a TX/RX pair that can be used for GPS
Pull up on nCS recommended for proper power sequencing.
SHA-256 Crypto Chip, RNG, and Secure 4.5Kb EEPROM

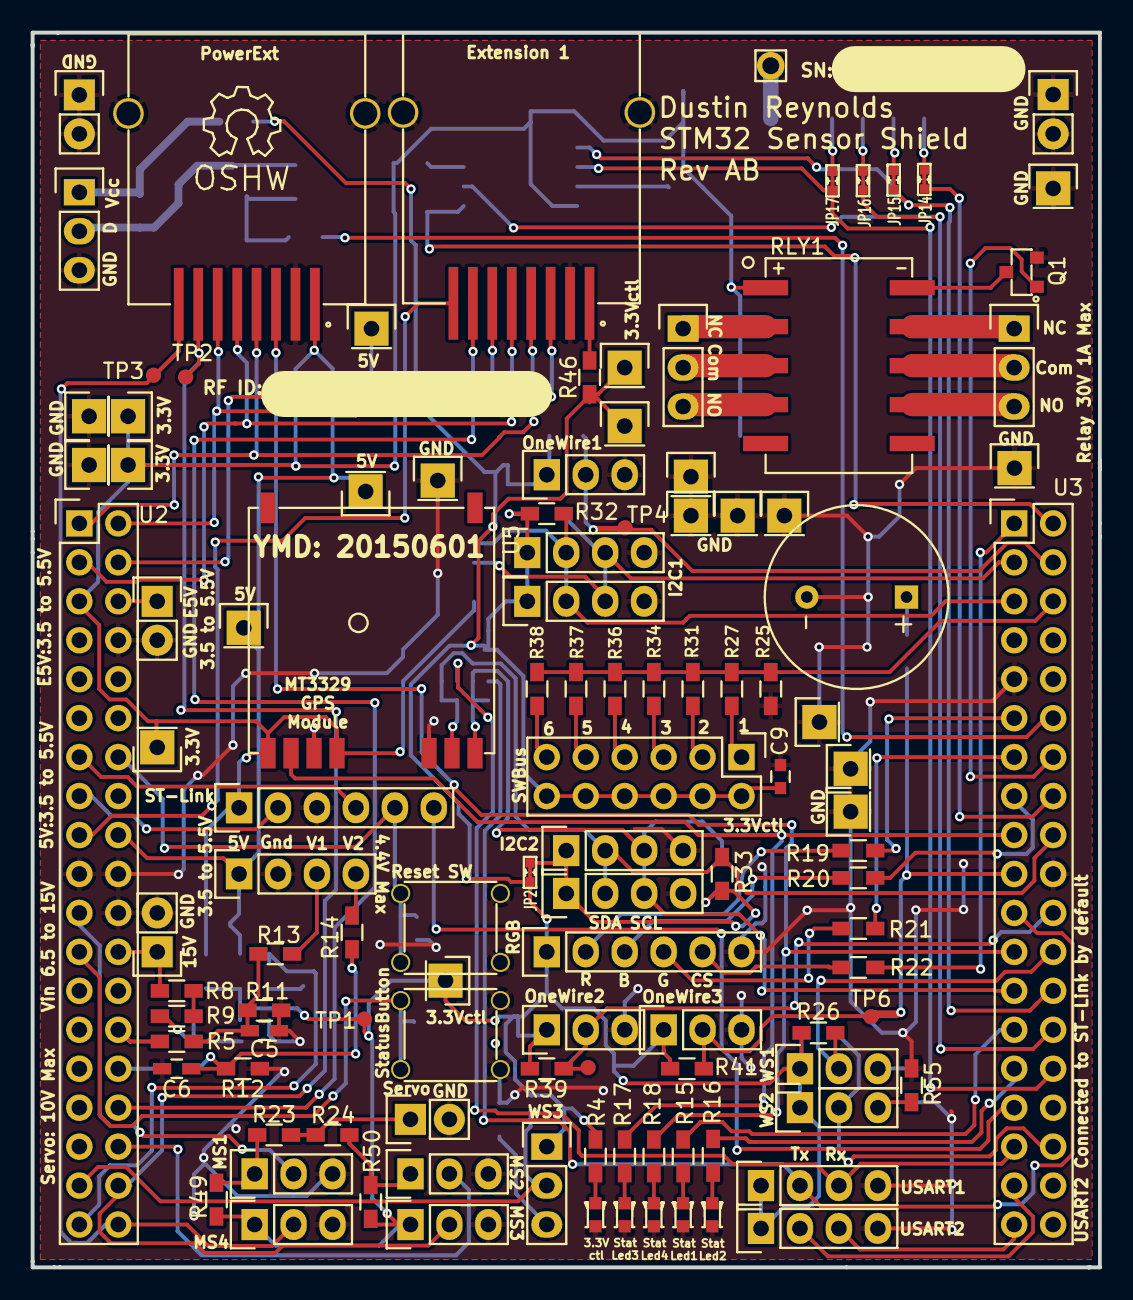
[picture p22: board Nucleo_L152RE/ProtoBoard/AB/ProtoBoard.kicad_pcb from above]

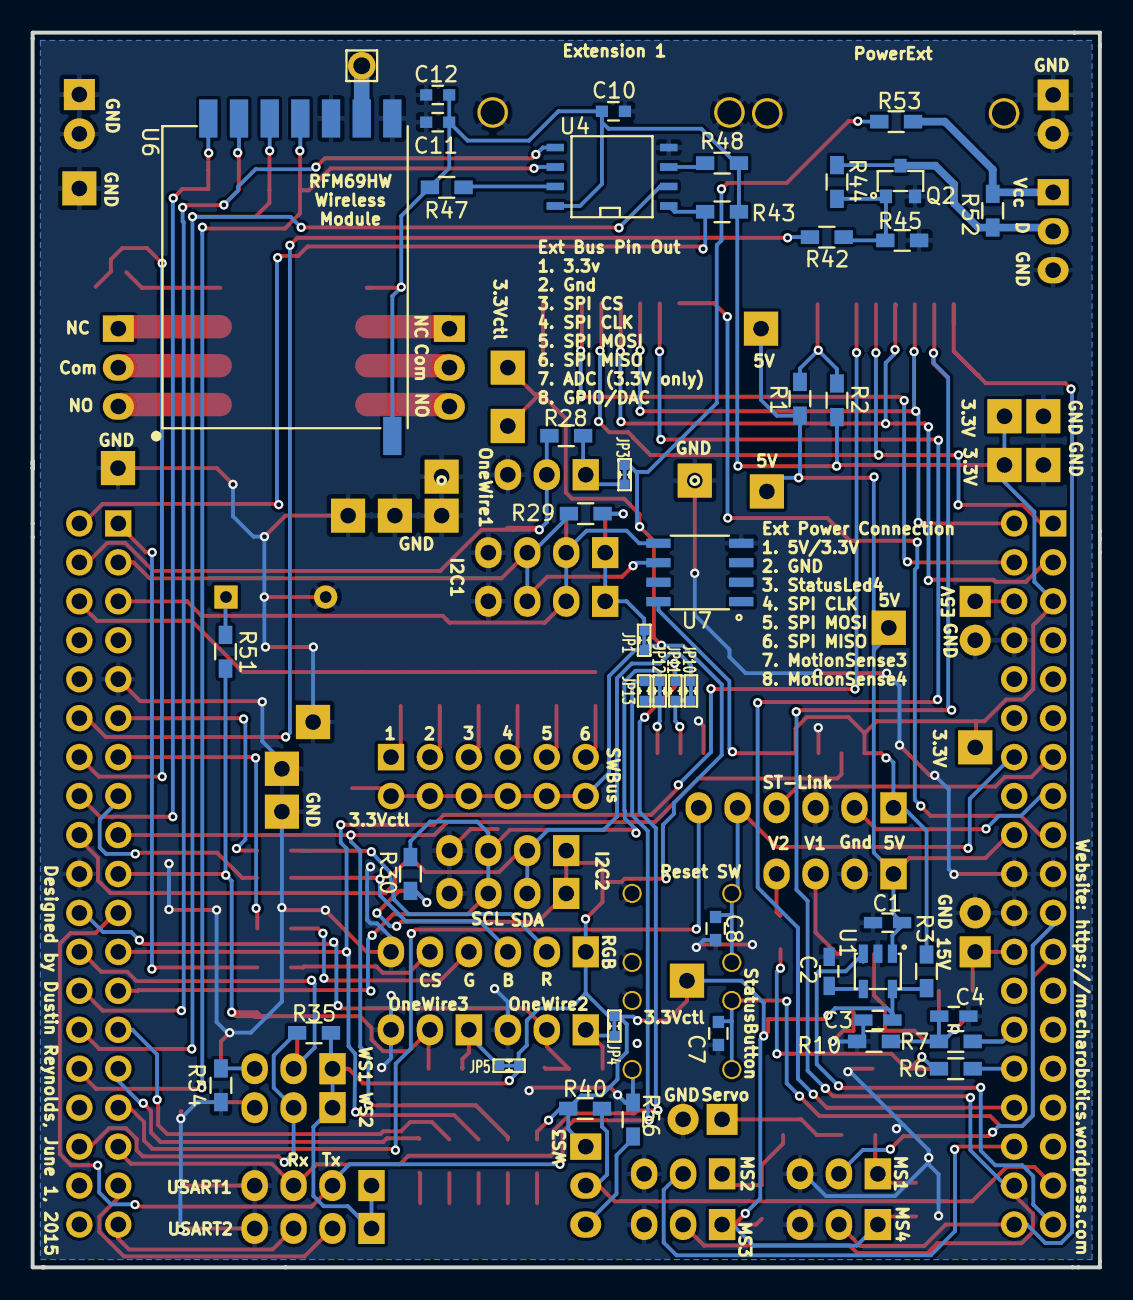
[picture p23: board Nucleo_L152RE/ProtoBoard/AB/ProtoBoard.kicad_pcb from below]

Board: 2 copper layers, 69.6 x 80.5 mm, 158 parts (44 on the bottom side), 98 nets.

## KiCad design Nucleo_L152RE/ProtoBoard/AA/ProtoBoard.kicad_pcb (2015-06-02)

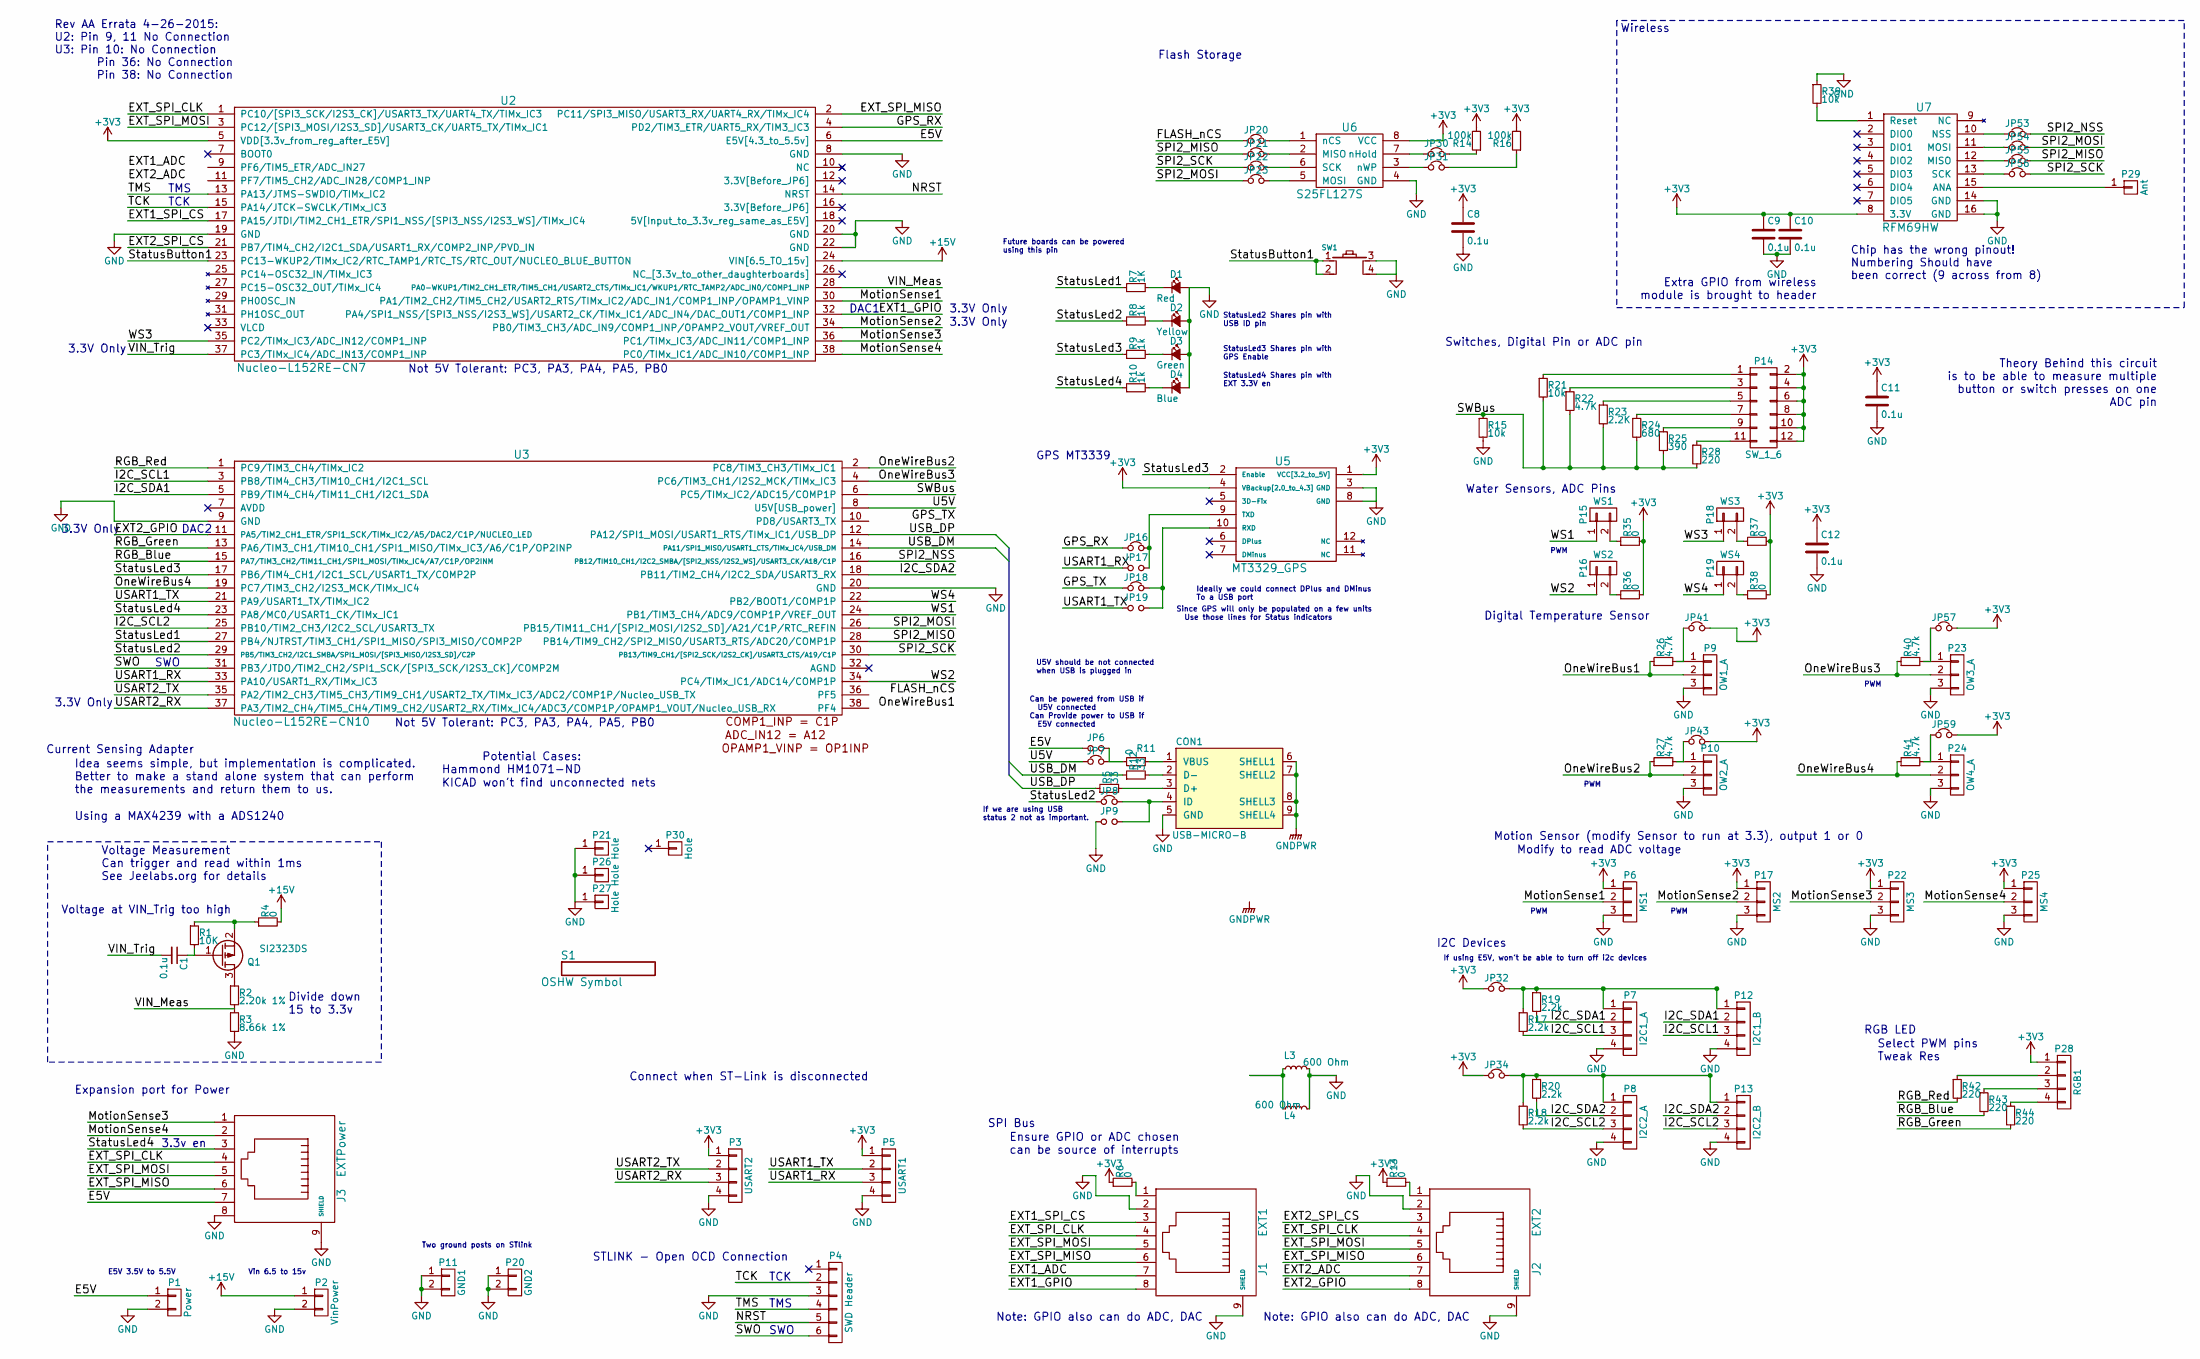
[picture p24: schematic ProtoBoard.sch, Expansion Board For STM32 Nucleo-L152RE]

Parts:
C1: 0.1u; C_0603_HandSoldering; Digikey Part Number 490-1532-1-ND
C8, C9, C10, C11, C12: 0.1u; C_0603; Digikey Part Number 490-1532-1-ND
CON1: USB-MICRO-B; USB_micro_AB; Digikey Part Number 609-4053-1-ND
D1: Red; LED_0603; Digikey Part Number 160-1447-1-ND
D2: Yellow; LED_0603; Digikey Part Number 160-1448-1-ND
D3: Green; LED_0603; Digikey Part Number 160-1446-1-ND
D4: Blue; LED_0603; Digikey Part Number 160-1647-1-ND
J1: EXT1; RJ45_SMD; Digikey Part Number RJLSE4238101TTR-ND
J2: EXT2; RJ45_SMD; Digikey Part Number RJLSE4238101TTR-ND
J3: EXTPower; RJ45_SMD; Digikey Part Number RJLSE4238101TTR-ND
JP6, JP9, JP17, JP19: Jumper_NO_Small; SB_NO
JP7, JP8, JP16, JP18, JP20, JP21, JP22, JP23, JP30, JP31, JP32, JP34, JP41, JP43, JP53, JP54, JP55, JP56, JP57, JP59: Jumper_NC_Small; SB_NC
L3, L4: 600 Ohm; R_0603_HandSoldering; Digikey Part Number 240-2371-1-ND
P1: Power; Pin_Header_Straight_1x02
P2: VinPower; Pin_Header_Straight_1x02
P3: USART2; Pin_Header_Straight_1x04
P4: SWD Header; Pin_Header_Straight_1x06
P5: USART1; Pin_Header_Straight_1x04
P6: MS1; Pin_Header_Straight_1x03
P7: I2C1_A; Pin_Header_Straight_1x04
P8: I2C2_A; Pin_Header_Straight_1x04
P9: OW1_A; Pin_Header_Straight_1x03
P10: OW2_A; Pin_Header_Straight_1x03
P11: GND1; Pin_Header_Straight_1x02
P12: I2C1_B; Pin_Header_Straight_1x04
P13: I2C2_B; Pin_Header_Straight_1x04
P14: SW_1_6; Pin_Header_Straight_2x06
P15: WS1; Pin_Header_Straight_1x02
P16: WS2; Pin_Header_Straight_1x02
P17: MS2; Pin_Header_Straight_1x03
P18: WS3; Pin_Header_Straight_1x02
P19: WS4; Pin_Header_Straight_1x02
P20: GND2; Pin_Header_Straight_1x02
P21, P26, P27: Hole; plat_hole_4_20
P22: MS3; Pin_Header_Straight_1x03
P23: OW3_A; Pin_Header_Straight_1x03
P24: OW4_A; Pin_Header_Straight_1x03
P25: MS4; Pin_Header_Straight_1x03
P28: RGB1; Pin_Header_Straight_1x04
P29: Ant; Pin_Header_Straight_1x01
P30: Hole; MountingHole_3mm
Q1: SI2323DS; TO-236; Digikey Part Number SI2323DS-T1-E3CT-ND
R1: 10K; R_0603_HandSoldering; Digikey Part Number P10KGCT-ND
R2: 2.20k 1%; R_0603_HandSoldering; Digikey Part Number P2.20KHCT-ND
R3: 8.66k 1%; R_0603_HandSoldering; Digikey Part Number P8.66KHCT-ND
R4, R6, R13, R35, R36, R37, R38: 0; R_0603_HandSoldering; Digikey Part Number P0.0GCT-ND
R5, R12: 33; R_0603_HandSoldering; Digikey Part Number P33HCT-ND
R7: 1K; R_0603_HandSoldering; Digikey Part Number P1.0KGCT-ND
R8, R9, R10: 1k; R_0603_HandSoldering; Digikey Part Number P1.0KGCT-ND
R11: 0; R_0603_HandSoldering; Digikey Part Number P0.0HCT-ND
R14, R16: 100k; R_0603_HandSoldering; Digikey Part Number RMCF0603FT100KTR-ND
R15, R21, R39: 10k; R_0603_HandSoldering; Digikey Part Number P10KGCT-ND
R17, R18, R19, R20: 2.2k; R_0603_HandSoldering; Digikey Part Number P2.2KGCT-ND
R22: 4.7K; R_0603_HandSoldering; Digikey Part Number P4.7KGCT-ND
R23: 2.2K; R_0603_HandSoldering; Digikey Part Number P2.2KGCT-ND
R24: 680; R_0603_HandSoldering; Digikey Part Number P680GCT-ND
R25: 390; R_0603_HandSoldering; Digikey Part Number P390GCT-ND
R26, R27, R40, R41: 4.7k; R_0603_HandSoldering; Digikey Part Number P4.7KGCT-ND
R28, R42, R43, R44: 220; R_0603_HandSoldering; Digikey Part Number P220GCT-ND
S1: OSHW Symbol; Symbol_OSHW-Logo_SilkScreen
SW1: MomentarySwitch; Tact_switch; Digikey Part Number 450-1650-ND
U2: Nucleo-L152RE-CN7; Pin_Header_Straight_2x19; Digikey Part Number 497-14363-ND
U3: Nucleo-L152RE-CN10; Pin_Header_Straight_2x19
U5: MT3329_GPS; MT3329
U6: S25FL127S; SOIC-8-FLASH; Digikey Part Number 1274-1045-ND
U7: RFM69HW

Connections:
+3V3: C8.1, C9.1, C10.1, C11.1, C12.1, JP32.1, JP34.1, JP41.2, JP43.2, JP57.2, JP59.2, P3.1, P5.1, P6.1, P14.2, P14.4, P14.6, P14.8, P14.10, P14.12, P17.1, P22.1, P25.1, P28.1, R6.1, R13.1, R14.2, R16.2, R35.2, R36.2, R37.2, R38.2, U2.5 (VDD[3.3v_from_reg_after_E5V]), U5.1 (VCC[3.2_to_5V]), U5.4 (VBackup[2.0_to_4.3]), U6.8 (VCC), U7.8 (3.3V)
+15V: P2.1, R4.2, U2.24 (VIN[6.5_TO_15v])
/E5V: J3.7, JP6.1, P1.1, U2.6 (E5V[4.3_to_5.5v])
/EXT1_ADC: J1.7, U2.9 (PF6/TIM5_ETR/ADC_IN27)
/EXT1_GPIO: J1.8, U2.32 (PA4/SPI1_NSS/[SPI3_NSS/I2S3_WS]/USART2_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)
/EXT1_SPI_CS: J1.3, U2.17 (PA15/JTDI/TIM2_CH1_ETR/SPI1_NSS/[SPI3_N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)
/EXT2_ADC: J2.7, U2.11 (PF7/TIM5_CH2/ADC_IN28/COMP1_INP)
/EXT2_GPIO: J2.8, U3.11 (PA5/TIM2_CH1_ETR/SPI1_SCK/TIMx_IC2/A5/D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)
/EXT2_SPI_CS: J2.3, U2.21 (PB7/TIM4_CH2/I2C1_SDA/USART1_RX/COMP2_I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)
/EXT_SPI_CLK: J1.4, J2.4, J3.4, U2.1 (PC10/[SPI3_SCK/I2S3_CK]/USART3_TX/UART4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)
/EXT_SPI_MISO: J1.6, J2.6, J3.6, U2.2 (PC11/SPI3_MISO/USART3_RX/UART4_RX/TIMx_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)
/EXT_SPI_MOSI: J1.5, J2.5, J3.5, U2.3 (PC12/[SPI3_MOSI/I2S3_SD]/USART3_CK/UART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)
/FLASH_nCS: JP20.1, U3.36 (PF5)
/GPS_RX: JP16.1, U2.4 (PD2/TIM3_ETR/UART5_RX/TIM3_IC3)
/GPS_TX: JP18.1, U3.10 (PD8/USART3_TX)
/I2C_SCL1: P7.3, P12.3, R17.2, U3.3 (PB8/TIM4_CH3/TIM10_CH1/I2C1_SCL)
/I2C_SCL2: P8.3, P13.3, R18.2, U3.25 (PB10/TIM2_CH3/I2C2_SCL/USART3_TX)
/I2C_SDA1: P7.2, P12.2, R19.2, U3.5 (PB9/TIM4_CH4/TIM11_CH1/I2C1_SDA)
/I2C_SDA2: P8.2, P13.2, R20.2, U3.18 (PB11/TIM2_CH4/I2C2_SDA/USART3_RX)
/MotionSense1: P6.2, U2.30 (PA1/TIM2_CH2/TIM5_CH2/USART2_RTS/TIMx_I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)
/MotionSense2: P17.2, U2.34 (PB0/TIM3_CH3/ADC_IN9/COMP1_INP/OPAMP2_V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)
/MotionSense3: J3.1, P22.2, U2.36 (PC1/TIMx_IC3/ADC_IN11/COMP1_INP)
/MotionSense4: J3.2, P25.2, U2.38 (PC0/TIMx_IC1/ADC_IN10/COMP1_INP)
/NRST: P4.5, U2.14 (NRST)
/OneWireBus1: P9.2, R26.1, U3.38 (PF4)
/OneWireBus2: P10.2, R27.1, U3.2 (PC8/TIM3_CH3/TIMx_IC1)
/OneWireBus3: P23.2, R40.1, U3.4 (PC6/TIM3_CH1/I2S2_MCK/TIMx_IC3)
/OneWireBus4: P24.2, R41.1, U3.19 (PC7/TIM3_CH2/I2S3_MCK/TIMx_IC4)
/RGB_Blue: R43.2, U3.15 (PA7/TIM3_CH2/TIM11_CH1/SPI1_MOSI/TIMx_I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)
/RGB_Green: R44.2, U3.13 (PA6/TIM3_CH1/TIM10_CH1/SPI1_MISO/TIMx_I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)
/RGB_Red: R42.2, U3.1 (PC9/TIM3_CH4/TIMx_IC2)
/SPI2_MISO: JP21.1, JP55.2, U3.28 (PB14/TIM9_CH2/SPI2_MISO/USART3_RTS/ADC2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)
/SPI2_MOSI: JP23.1, JP54.2, U3.26 (PB15/TIM11_CH1/[SPI2_MOSI/I2S2_SD]/A21/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)
/SPI2_NSS: JP53.2, U3.16 (PB12/TIM10_CH1/I2C2_SMBA/[SPI2_NSS/I2S2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)
/SPI2_SCK: JP22.1, JP56.2, U3.30 (PB13/TIM9_CH1/[SPI2_SCK/I2S2_CK]/USART3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)
/SWBus: R15.1, R21.2, R22.2, R23.2, R24.2, R25.2, R28.2, U3.6 (PC5/TIMx_IC2/ADC15/COMP1P)
/SWO: P4.6, U3.31 (PB3/JTDO/TIM2_CH2/SPI1_SCK/[SPI3_SCK/I2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)
/StatusButton1: SW1.1, SW1.2, U2.23 (PC13-WKUP2/TIMx_IC2/RTC_TAMP1/RTC_TS/RT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)
/StatusLed1: R7.1, U3.27 (PB4/NJTRST/TIM3_CH1/SPI1_MISO/SPI3_MISO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)
/StatusLed2: JP8.1, R8.1, U3.29 (PB5/TIM3_CH2/I2C1_SMBA/SPI1_MOSI/[SPI3_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)
/StatusLed3: R9.1, U3.17 (PB6/TIM4_CH1/I2C1_SCL/USART1_TX/COMP2P), U5.2 (Enable)
/StatusLed4: J3.3, R10.1, U3.23 (PA8/MC0/USART1_CK/TIMx_IC1)
/TCK: P4.2, U2.15 (PA14/JTCK-SWCLK/TIMx_IC3)
/TMS: P4.4, U2.13 (PA13/JTMS-SWDIO/TIMx_IC2)
/U5V: JP7.1, U3.8 (U5V[USB_power])
/USART1_RX: JP17.1, P5.3, U3.33 (PA10/USART1_RX/TIMx_IC3)
/USART1_TX: JP19.1, P5.2, U3.21 (PA9/USART1_TX/TIMx_IC2)
/USART2_RX: P3.3, U3.37 (PA3/TIM2_CH4/TIM5_CH4/TIM9_CH2/USART2_R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)
/USART2_TX: P3.2, U3.35 (PA2/TIM2_CH3/TIM5_CH3/TIM9_CH1/USART2_T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)
/USB_DM: R12.1, U3.14 (PA11/SPI1_MISO/USART1_CTS/TIMx_IC4/USB_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)
/USB_DP: R5.1, U3.12 (PA12/SPI1_MOSI/USART1_RTS/TIMx_IC1/USB_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)
/VIN_Meas: R2.2, R3.1, U2.28 (PA0-WKUP1/TIM2_CH1_ETR/TIM5_CH1/USART2_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)
/VIN_Trig: C1.2, U2.37 (PC3/TIMx_IC4/ADC_IN13/COMP1_INP)
/WS1: P15.1, U3.24 (PB1/TIM3_CH4/ADC9/COMP1P/VREF_OUT)
/WS2: P16.1, U3.34 (PC4/TIMx_IC1/ADC14/COMP1P)
/WS3: P18.1, U2.35 (PC2/TIMx_IC3/ADC_IN12/COMP1_INP)
/WS4: P19.1, U3.22 (PB2/BOOT1/COMP1P)
GND: C8.2, C9.2, C10.2, C11.2, C12.2, CON1.5 (GND), D1.2 (A), D2.2 (A), D3.2 (A), D4.2 (A), J1.2, J1.9 (SHIELD), J2.2, J2.9 (SHIELD), J3.8, J3.9 (SHIELD), JP9.1, L3.2, L4.2, P1.2, P2.2, P3.4, P4.3, P5.4, P6.3, P7.4, P8.4, P9.3, P10.3, P11.1, P11.2, P12.4, P13.4, P17.3, P20.1, P20.2, P21.1, P22.3, P23.3, P24.3, P25.3, P26.1, P27.1, R3.2, R15.2, R39.1, SW1.3, SW1.4, U2.8 (GND), U2.19 (GND), U2.20 (GND), U2.22 (GND), U3.9 (GND), U3.20 (GND), U5.3 (GND), U5.8 (GND), U6.4 (GND), U7.14 (GND), U7.16 (GND)
unnamed: C1.1, Q1.1 (G), R1.2
unnamed: CON1.1 (VBUS), R11.1
unnamed: CON1.2 (D-), R12.2
unnamed: CON1.3 (D+), R5.2
unnamed: CON1.4 (ID), JP8.2, JP9.2
unnamed: D1.1 (K), R7.2
unnamed: D2.1 (K), R8.2
unnamed: D3.1 (K), R9.2
unnamed: D4.1 (K), R10.2
unnamed: J1.1, R6.2
unnamed: J2.1, R13.2
unnamed: JP6.2, JP7.2, R11.2
unnamed: JP16.2, JP17.2, U5.9 (TXD)
unnamed: JP18.2, JP19.2, U5.10 (RXD)
unnamed: JP20.2, U6.1 (nCS)
unnamed: JP21.2, U6.2 (MISO)
unnamed: JP22.2, U6.6 (SCK)
unnamed: JP23.2, U6.5 (MOSI)
unnamed: JP30.1, U6.7 (nHold)
unnamed: JP30.2, R14.1
unnamed: JP31.1, U6.3 (nWP)
unnamed: JP31.2, R16.1
unnamed: JP32.2, P7.1, P12.1, R17.1, R19.1
unnamed: JP34.2, P8.1, P13.1, R18.1, R20.1
unnamed: JP41.1, P9.1, R26.2
unnamed: JP43.1, P10.1, R27.2
unnamed: JP53.1, U7.10 (NSS)
unnamed: JP54.1, U7.11 (MOSI)
unnamed: JP55.1, U7.12 (MISO)
unnamed: JP56.1, U7.13 (SCK)
unnamed: JP57.1, P23.1, R40.2
unnamed: JP59.1, P24.1, R41.2
unnamed: P14.1, R21.1
unnamed: P14.3, R22.1
unnamed: P14.5, R23.1
unnamed: P14.7, R24.1
unnamed: P14.9, R25.1
unnamed: P14.11, R28.1
unnamed: P15.2, R35.1
unnamed: P16.2, R36.1
unnamed: P18.2, R37.1
unnamed: P19.2, R38.1
unnamed: P28.2, R42.1
unnamed: P28.3, R43.1
unnamed: P28.4, R44.1
unnamed: P29.1, U7.15 (ANA)
unnamed: Q1.2 (S), R1.1, R4.1
unnamed: Q1.3 (D), R2.1
unnamed: R39.2, U7.1 (Reset)

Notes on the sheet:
TCK
TMS
SWO
Wireless
Connect when ST-Link is disconnected
Not 5V Tolerant: PC3, PA3, PA4, PA5, PB0
Switches, Digital Pin or ADC pin
Water Sensors, ADC Pins
Digital Temperature Sensor
Motion Sensor (modify Sensor to run at 3.3), output 1 or 0
Current Sensing Adapter
STLINK - Open OCD Connection
Theory Behind this circuit is to be able to measure multiple button or switch presses on one ADC pin
Flash Storage
Idea seems simple, but implementation is complicated. Better to make a stand alone system that can perform the measurements and return them to us.
Using a MAX4239 with a ADS1240
If using E5V, won't be able to turn off i2c devices
Extra GPIO from wireless module is brought to header
Potential Cases: Hammond HM1071-ND
SPI Bus
Ensure GPIO or ADC chosen can be source of interrupts
RGB LED
Select PWM pins Tweak Res
Voltage Measurement Can trigger and read within 1ms See Jeelabs.org for details
Divide down 15 to 3.3v
DAC2
DAC1
Note: GPIO also can do ADC, DAC
U5V should be not connected when USB is plugged in
Ideally we could connect DPlus and DMinus To a USB port
Vin 6.5 to 15v
E5V 3.5V to 5.5V
If we are using USB status 2 not as important.
I2C Devices
StatusLed2 Shares pin with USB ID pin
Can be powered from USB if U5V connected Can Provide power to USB if E5V connected
PWM
GPS MT3339
Future boards can be powered using this pin
Since GPS will only be populated on a few units Use those lines for Status indicators

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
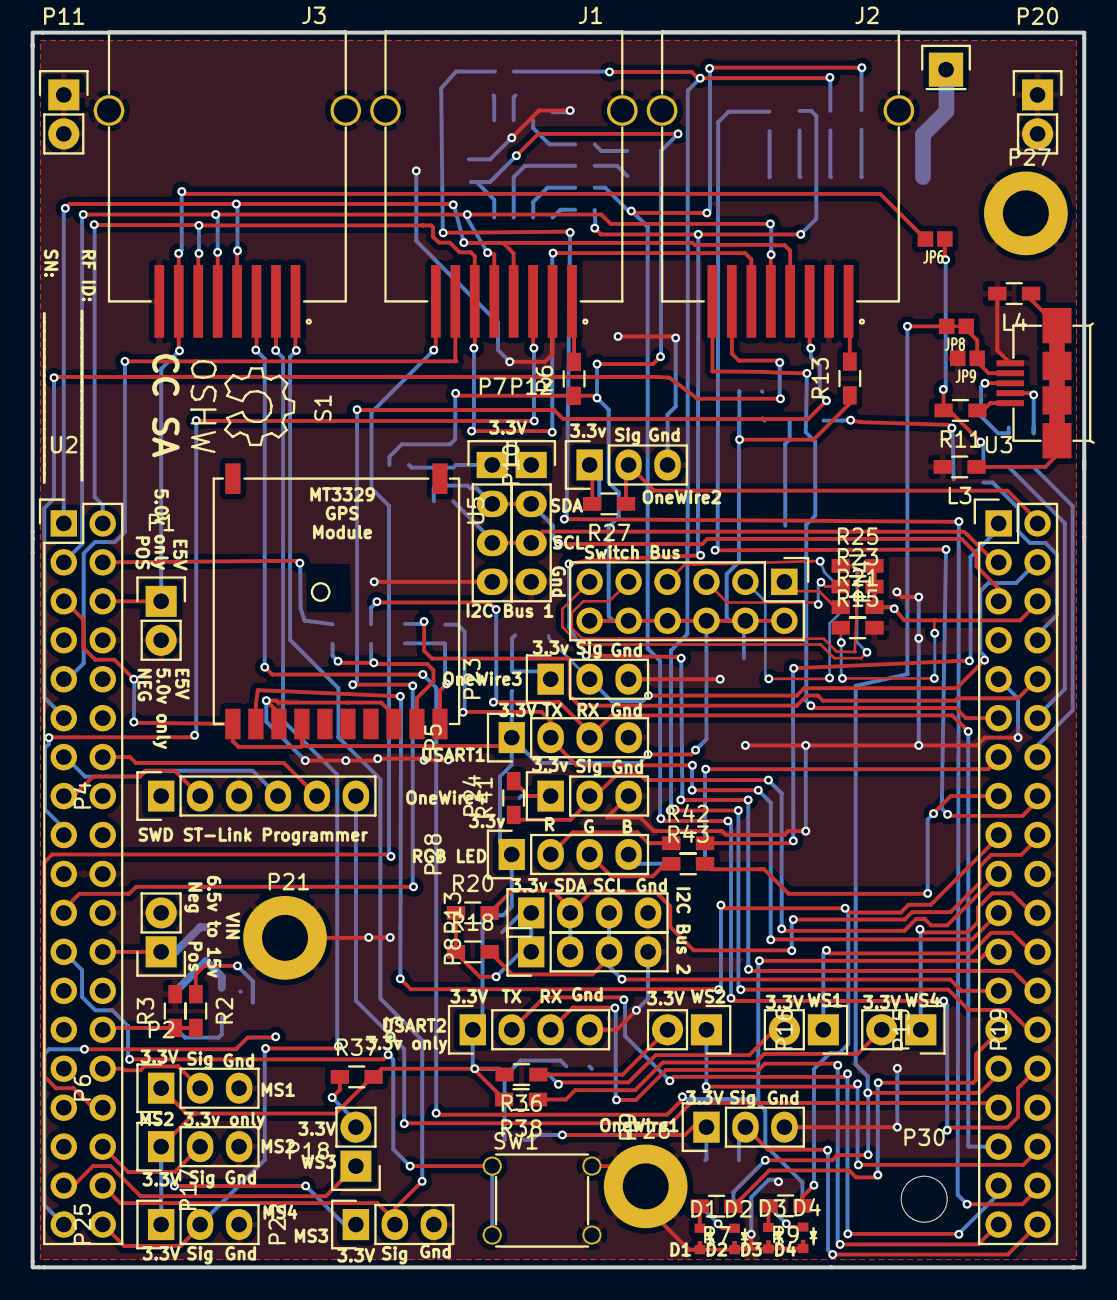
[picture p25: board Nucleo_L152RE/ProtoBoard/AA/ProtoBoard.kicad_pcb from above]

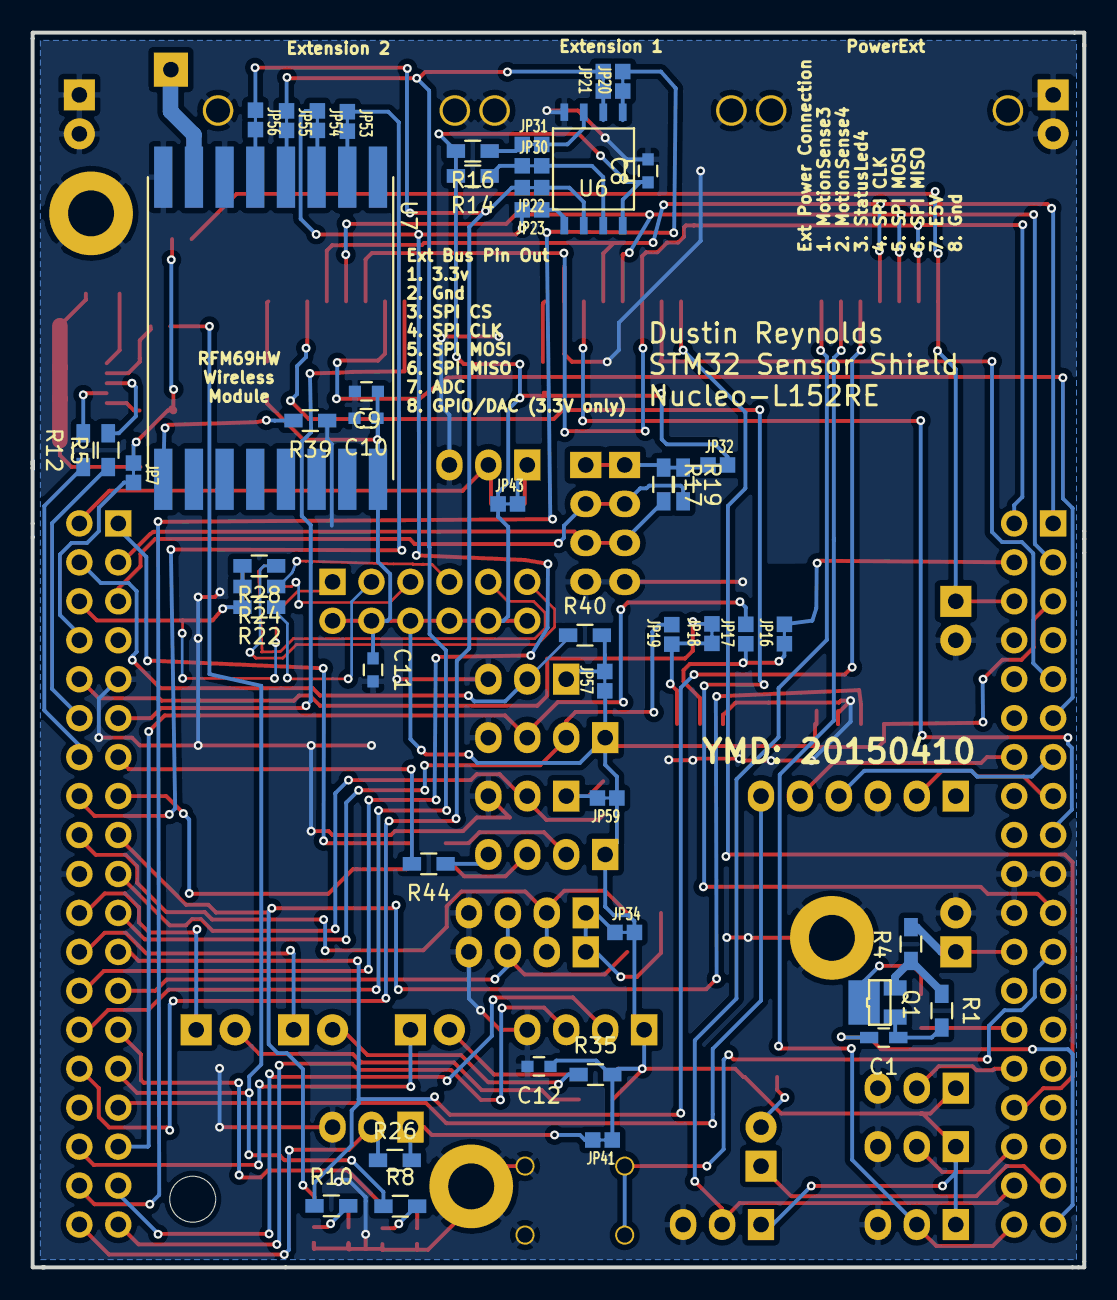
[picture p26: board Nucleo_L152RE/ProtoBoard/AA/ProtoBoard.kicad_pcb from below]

Board: 2 copper layers, 68.6 x 80.5 mm, 116 parts (48 on the bottom side), 108 nets.

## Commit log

2015-03-29 Initial commit, board passed DRC
    [CurrentSenseCalc.xlsx, ProtoBoard.kicad_pcb, ProtoBoard.sch]
2015-03-30 Have more of the components layout and specified.
    [ProtoBoard.sch]
2015-03-31 Have all footprints selected for components, now starting to organize parts on board.
    [ProtoBoard.kicad_pcb, ProtoBoard.sch]
2015-04-01 Removed many jumper bridges, starting to get a feel for how many components there will be and where they will be.
    [ProtoBoard.kicad_pcb, ProtoBoard.sch]
2015-04-02 Saving initial schematic. I plan on removing power regulators to make the board simpler to design and layout. Voltage regulation can happen off board.
2015-04-03 About to remove a few extra connectors.
    [ProtoBoard.kicad_pcb, ProtoBoard.sch]
2015-04-03 all remaining components fit on one board.
    [ProtoBoard.kicad_pcb, ProtoBoard.sch]
2015-04-04 performing more routing of the board. This board is quickly becoming complicated with all of the headers to navigate around.
    [ProtoBoard.kicad_pcb, ProtoBoard.sch]
2015-04-04 All signals routed, now the only remaining thing is ground signals and/or ground planes.
    [ProtoBoard.kicad_pcb, ProtoBoard.sch]
2015-04-04 All pads now connected.
    [ProtoBoard.kicad_pcb]
2015-04-05 About to modify Solder Bridges to be a smaller 0402 package rather than the custom one which generates DRC errors.
    [ProtoBoard.kicad_pcb, ProtoBoard.sch]
2015-04-05 In process of checking all footprints. Found mistake in usb micro AB footprint.
    [ProtoBoard.kicad_pcb]
2015-04-05 Fixed Flash and Pmos footprints. Added symbol part for schematic.
    [ProtoBoard.kicad_pcb, ProtoBoard.sch]
2015-04-05 Commit just before implementing groundplanes.
    [ProtoBoard.kicad_pcb]
2015-04-05 Ground plane implemented on 2 layers.
    [ProtoBoard.kicad_pcb]
2015-04-05 Adding licensing to Pcbnew.
2015-04-06 Testing inserting metadata into schematics about parts used for BOM generation.
2015-04-06 Adding part details to schematic, creating BOM tools.
    [ProtoBoard.sch, ProtoBoard_BOM.csv]
2015-04-07 Updated schematic with links to almost all parts.
    [ProtoBoard.sch, ProtoBoard_BOM.csv]
2015-04-07 Adding BOM and final schematics.
2015-04-08 Ordered parts from Mouser for Protoboard AA.
    [2015_04_07-MouserBomOrdered.ods, ProtoBoard.sch, ProtoBoard_BOM.csv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]
2015-04-10 Submitted first printing of AA version. Uploading Gerbers since we would like to be able to get back to this point.
    [ProtoBoard-B_Cu.GBL, ProtoBoard-B_Mask.GBS, ProtoBoard-B_Paste.GBP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]
2015-04-10 Moved entire repository to another folder to test the ability to load libraries, schematics, pcb. Success.
2015-04-11 Changing some documentation on schematic's.
    [$ProtoBoard.sch]
2015-04-11 Add PDF schematics.
2015-04-27 Found 5 unconnected pins on Nucleo L152RE, so I've added an Errata and deleted the wires for the effected nets.
    [ProtoBoard.sch]
2015-05-12 Adding notes to schematic and board layout to indicate the very broken wireless module interface. New board will need to be created to fix the issue.
    [ProtoBoard.kicad_pcb, ProtoBoard.sch]
2015-05-18 Making more changes on Rev AB. Found that the voltage measurement circuit didn't work as expected, so it has been replaced with a voltage divider. Removing second Ethernet port since they take up a l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
    [ProtoBoard.kicad_pcb, ProtoBoard.sch]
2015-05-23 Split schematic into multiple pages. Added servo power input and calculated voltage dividers for ADC measurements with capacitors so that the measurements can be read by the ADC.
    [Modules.sch, NucleoPins.sch, Power.sch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]
2015-05-23 Adding datasheet for LDS3985 3.3V LDO regulator
2015-05-27 Components mostly laid out into final resting positions with exception of plethora of single pin connections for easily connecting to GND, 3.3V, 5V, 3.3Vctl.
    [Modules.sch, NucleoPins.sch, Power.sch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]
2015-05-28 One of the connectors is routed, now to do the other one.
    [ProtoBoard.kicad_pcb]
2015-05-29 Added many traces which will have to be removed since I put via's on pads :/
    [Modules.sch, ProtoBoard.kicad_pcb, Sensors.sch]
2015-05-31 Final draft with all traces and artwork in place.
    [Modules.sch, NucleoPins.sch, Power.sch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]
2015-06-02 Finished AB board.
    [Modules.sch, NucleoPins.sch, Power.sch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]
2015-06-03 Updated MFG part numbers on schematic for BOM generation.
    [Modules.sch, Sensors.sch]

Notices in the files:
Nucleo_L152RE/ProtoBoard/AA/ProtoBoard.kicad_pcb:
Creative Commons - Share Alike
